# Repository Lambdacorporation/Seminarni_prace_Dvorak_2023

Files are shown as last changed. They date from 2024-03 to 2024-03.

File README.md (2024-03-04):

# Seminární práce Dvořák 2023
Tato práce je zaměřena na vytvoření vlastního fyzického 3D modelu v podobě simulátoru křižovatky ovládané jednodeskovými počítači a mikrokontrolery Raspberry Pi, které jsou propojeny pomocí SSH protokolu, a dalšími kompatibilními komponenty. Další nedílnou součástí tohoto simulátoru je Python aplikace, která slouží a je programována jako přehledný ovládací panel na sedmipalcovém multikapacitním displeji. Jejím hlavním účelem je možnost procvičování řady otázek týkajících se pravidel silničního provozu na křižovatkách.

Klíčová slova: Raspberry Pi; křižovatka; 3D simulátor; Python; SSH protokol; dotykový displej; krokový motor; auto

This project is focused on creating a custom physical 3D model in the form of an intersection simulator controlled by single-board computers and Raspberry Pi microcontrollers connected through the SSH protocol, along with other compatible components. Another integral part of this simulator is a Python application designed and programmed as a user-friendly control panel on a seven-inch multitouch display. Its main purpose is to provide the ability to practice a series of questions related to traffic rules at intersections. 

Keywords: Raspberry Pi; traffic intersection; 3D simulator; Python; SSH protocol; multitouch display; stepper motor; car

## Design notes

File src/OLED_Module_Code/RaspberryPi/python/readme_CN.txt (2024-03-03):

/*****************************************************************************
* | File      	:   Readme_CN.txt
* | Author      :   Waveshare team
* | Function    :   Help with use
* | Info        :
*----------------
* |	This version:   V1.0
* | Date        :   2020-08-28
* | Info        :   在这里提供一个中文版本的使用文档，以便你的快速使用
******************************************************************************/
这个文件是帮助您使用本例程。
由于我们的OLED屏越来越多，不便于我们的维护，因此把所有的OLED程序做成一个工程。
在这里简略的描述本工程的使用：

1.基本信息：
本例程基于树莓派4B+开发的，内核版本
	Linux raspberrypi 5.4.51-v7l+ #1333 SMP Mon Aug 10 16:51:40 BST 2020 armv7l GNU/Linux
你可以在工程的examples\中查看对应的测试例程;

2.管脚连接：
管脚连接你可以在\lib\waveshare_OLED\config.py中查看，这里也再重述一次：
SPI:
	OLED   =>    RPI(BCM)
	VCC    ->    3.3
	GND    ->    GND
	DIN    ->    10(MOSI)
	CLK    ->    11(SCLK)
	CS     ->    8
	DC     ->    25
	RST    ->    27

IIC:
	OLED   =>    RPI(BCM)
	VCC    ->    3.3
	GND    ->    GND
	DIN    ->    2(SDA)
	CLK    ->    3(SCL)
	CS     ->    8
	DC     ->    25
	RST    ->    27

3.安装库：
    sudo apt-get update
    sudo apt-get install python-pip
    sudo apt-get install python-pil
    sudo apt-get install python-numpy
    sudo pip install RPi.GPIO

或

    sudo apt-get update
    sudo apt-get install python3-pip
    sudo apt-get install python3-pil
    sudo apt-get install python3-numpy
    sudo pip3 install RPi.GPIO

4.基本使用：
由于本工程是一个综合工程，对于使用而言，你可能需要阅读以下内容：
你可以在examples\目录中查看测试程序
请注意你购买的是哪一款的OLED。
栗子1：
    如果你购买的1.3inch OLED Module (C)，那么你应该执行命令：
		sudo python OLED_1in3_c_test.py
	或
		sudo python3 OLED_1in3_c_test.py
栗子2：
    如果你购买的1.5inch RGB OLED Module，那么你应该执行命令：
		sudo python OLED_1in5_rgb_test.py
	或
		sudo python3 OLED_1in5_rgb_test.py

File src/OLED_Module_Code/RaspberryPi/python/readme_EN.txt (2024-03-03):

/*****************************************************************************
* | File      	:   Readme_EN.txt
* | Author      :   Waveshare team
* | Function    :   Help with use
* | Info        :
*----------------
* |	This version:   V1.0
* | Date        :   2020-08-28
* | Info        :   Here is an English version of the documentation for your quick use.
******************************************************************************/
This file is to help you use this routine.
Since our OLED screens are getting more and more, it is not convenient for our maintenance, so all the OLED screen programs are made into one project.
A brief description of the use of this project is here:

1. Basic information:
This routine is based on the raspberry PI 4B+ development, the kernel version:
	Linux raspberrypi 5.4.51-v7l+ #1333 SMP Mon Aug 10 16:51:40 BST 2020 armv7l GNU/Linux
You can view the corresponding test routines in the examples\ of the project;

2. Pin connection:
Pin connections can be viewed in \lib\waveshare_OLED\config.py and will be repeated here:
SPI:
	OLED   =>    RPI(BCM)
	VCC    ->    3.3
	GND    ->    GND
	DIN    ->    10(MOSI)
	CLK    ->    11(SCLK)
	CS     ->    8
	DC     ->    25
	RST    ->    27

IIC:
	OLED   =>    RPI(BCM)
	VCC    ->    3.3
	GND    ->    GND
	DIN    ->    2(SDA)
	CLK    ->    3(SCL)
	CS     ->    8
	DC     ->    25
	RST    ->    27

3.Installation library
    sudo apt-get update
    sudo apt-get install python-pip
    sudo apt-get install python-pil
    sudo apt-get install python-numpy
    sudo pip install RPi.GPIO

or

    sudo apt-get update
    sudo apt-get install python3-pip
    sudo apt-get install python3-pil
    sudo apt-get install python3-numpy
    sudo pip3 install RPi.GPIO

4. Basic use:
Since this project is a comprehensive project, you may need to read the following for use:
You can view the test program in the examples\ directory.
Please note which OLED you purchased.
eg 1:
    if you bought 1.3inch OLED Module (C)，you should type：
		sudo python OLED_1in3_c_test.py
	or
		sudo python3 OLED_1in3_c_test.py
eg 2:
    if you bought 1.5inch RGB OLED Module，you should type：
		sudo python OLED_1in5_rgb_test.py
	or
		sudo python3 OLED_1in5_rgb_test.py

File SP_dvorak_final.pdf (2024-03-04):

## Gymnázium Třebíč

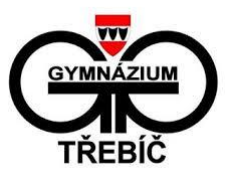
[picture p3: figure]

## Seminární práce z programování

## Simulace křižovatek pomocí fyzického 3D modelu

## Dominik Dvořák, 8.G

Vedoucí práce:
Ing. Lukáš Semerád Ph.D. | Třebíč 2023

Prohlašuji, že jsem při zpracování práce postupoval v souladu se zákonem 121/2000 Sb., o právu

autorském a o právech souvisejících s právem autorským v plném znění. Práci jsem vypracoval

samostatně pod vedením Ing. Lukáše Semeráda Ph.D. a použité zdroje informací jsem řádně uvedl

v Seznamu pramenů, Seznamu literatury a v seznamu Internetových zdrojů.

Třebíč 15. 12. 2023 | Dominik Dvořák

## Poděkování

Na tomto místě bych chtěl poděkovat všem, kteří mi s prací pomáhali a podporovali mě: v první

řadě vědecké skupině STRaDe při VUT Brno za možnost využití 3D tiskáren a poskytnutí cenných

rad k mé seminární práci, dále bych chtěl poděkovat své rodině za shovívavost a poskytnutí

podmínek k vypracování práce. A na závěr bych chtěl také poděkovat mému vedoucímu práce

a konzultantovi Ing. Lukáši Semerádovi Ph.D. za řadu cenných rad a odbornou konzultaci k mé

práci.

## Abstrakt

Tato práce je zaměřena na vytvoření vlastního fyzického 3D modelu v podobě simulátoru

křižovatky ovládané jednodeskovými počítači a mikrokontrolery Raspberry Pi, které jsou propojeny

pomocí SSH protokolu, a dalšími kompatibilními komponenty. Další nedílnou součástí tohoto

simulátoru je Python aplikace, která slouží a je programována jako přehledný ovládací panel na

sedmipalcovém multikapacitním displeji. Jejím hlavním účelem je možnost procvičování řady

otázek týkajících se pravidel silničního provozu na křižovatkách.

## Klíčová slova

Raspberry Pi; křižovatka; 3D simulátor; Python; SSH protokol; dotykový displej; krokový motor;

auto

## Abstract

This project is focused on creating a custom physical 3D model in the form of an intersection

simulator controlled by single-board computers and Raspberry Pi microcontrollers connected

through the SSH protocol, along with other compatible components. Another integral part of this

simulator is a Python application designed and programmed as a user-friendly control panel on

a seven-inch multitouch display. Its main purpose is to provide the ability to practice a series of

questions related to traffic rules at intersections.

## Keywords

Raspberry Pi; traffic intersection; 3D simulator; Python; SSH protocol; multitouch display; stepper

motor; car

Obsah

### ÚVOD

Tato práce se zabývá stavbou 3D fyzického simulátoru křižovatek, který má pomoci lépe

porozumět problematice pravidel silničního provozu na křižovatkách při výuce. Konkrétně

jsou využity při stavbě simulátoru pláty z 1 mm tlusté nerez oceli, jedno Raspberry Pi 4, čtyři

Raspberry Pi Zero, Raspberry Pi Pico WH, osm krokových motorů pro ovládání autíček na

vrchní desce a pro ovládání výhybek na ozubených drahách, čtyři OLED 1,5“ displeje pro

zobrazení dopravních značek, jeden 7“ dotykový displej, ozubené dráhy vytištěné z ABS

filamentu a moduly semaforů. Co se softwaru týče, tak je využit jako primární jazyk Python

a jeho knihovny, a SSH protokol. Práce uvádí také historii počítačů Raspberry Pi a rozbor

konkrétních modelů, dále také popisuje pravidla silničního provozu na křižovatkách.

V první části mé práce popisuji historii společnosti Raspberry Pi Foundation. Poté se věnuji

podrobnému popisu, představení a vlastnostem modelů Raspberry Pi a vybraným typům

operačních systémů, které jsou díky své jednoduchosti hardwaru a opensource licenci

dlouhodobě softwarově podporovány.

Druhá část práce je zaměřena na pravidla silničního provozu křižovatek. Zde zjišťuji, jaká

pravidla platí pro neoznačené křižovatky, ale převážně se věnuji dopravním značkám.

Dopravních značek je velké množství, ovšem křižovatek se týkají především dopravní značky

upravující přednost a světelné signalizační řízení. Toto řízení pomáhá s regulací provozu a je

užíváno převážně na vytížených místech. Všechny tyto vyhlášky nalezneme ve Sbírce zákonů ČR o provozu na pozemních komunikacích a o změnách některých zákonů (zákon o silničním

provozu).

Třetí částí je již samotné sestavení, vzhled a detailní popsání 3D simulátoru. K uvedení

simulátoru do provozu jsou potřeba krokové motory, OLED displeje, multitouch displej,

Raspberry Pi Zero WH, Raspberry Pi Pico WH a Raspberry Pi 4. Dalšími součástkami, které

zde nalezneme jsou například semafory, výhybky, ozubené koleje či modely aut. Tato auta

jezdí po vrchní desce modelu a jsou poháněna pomocí čtyř krokových motorů 28BYJ-48.

Zbylé motory ovládají „výhybky“ uprostřed simulátoru, které slouží k přesunutí autíčka na

jinou „ozubenou kolej“. Většina součástek byla vytištěna na 3D tiskárně pomocí 0,4 mm

filamentu ABS.

Poslední část mé práce věnuji operačnímu systému Raspberry OS, programovacímu jazyku

a komunikaci využité v simulátoru. Jako programovací jazyk celého modelu jsem zvolil

Python, který má na výběr velké množství knihoven. Všechny počítače Raspberry Pi spolu

komunikují pomocí SSH protokolu, který umožňuje rychlý a spolehlivý přenos příkazů.

V dnešní době známe mnoho způsobů, jak využít moderní techniku v reálném životě. Proto

mým prvním cílem při zpracovávání této práce je zvýšit povědomí o moderních možnostech

učení. Jako druhý cíl jsem si stanovil zdokonalení a prohloubení mých znalostí v oblasti

programování, představivosti a zručnosti.

### 1 RASPBERRY PI

Raspberry Pi je název pro řadu malých jednodeskových počítačů vyvíjených britskou

společností Raspberry Pi Foundation. Společnost založil Eben Upton jako neziskovou

organizaci v roce 2008 a jejím původním záměrem byl vývoj malých levných počítačů

sloužících pro výuku informatiky a robotiky ve školách. [57] [58]

Po vydání druhé generace Raspberry Pi se vytvořila dceřiná společnost Raspberry Pi Trading,

která převzala vývoj počítačů, zatímco Raspberry Pi Foundation se dále věnovala zpřístupnění

technologií co nejvíce studentům. [59]

## 1.1 Modely

Raspberry Pi Foundation dohromady vytvořila šestnáct modelů jednodeskových počítačů,

z kterých jsou k dnešnímu dni pouze tři oficiálně vyřazené a neprodejné (První generace

s 26pinovým GPIO a Raspberry Pi 4 s 1 GB RAM představená v roce 2019). Každý si může

vybrat pro své projekty ze spousty variant velikostí nebo výkonu.

### 1.1.1 Raspberry Pi model A a model B

První generace Raspberry Pi byla představena v roce 2012, a to ve dvou modelech, levnější

ale slabší model A a o něco dražší ale silnější model B. Model B byl uveden do prodeje v roce

2012, model A se o rok opozdil. [4]

Oba modely poháněl SoC čip BCM2835 od firmy Broadcom, postavený na jednojádrovém

procesoru ARM1176JZF-S od firmy ARM, a také obsahovaly 26pinový GPIO header, který

byl využit pouze v této generaci. Model A obsahoval 256 MB RAM a model B měl dvě

konfigurace RAM, jedna verze měla k dispozici také 256 MB a druhá dokonce 512 MB.

Model B navíc disponoval, oproti modelu A, ethernet portem a dvěma USB A porty namísto

jednoho, jinak byly modely i designem téměř identické. [4] [5] [6]

V roce 2014 Raspberry Pi Foundation uvedla do prodeje ještě vylepšené varianty první

generace Raspberry Pi. Nové modely dostaly označení Raspberry Pi A+ a Raspberry Pi B+.

Tyto vylepšené modely se lišily od základních velikostí operační paměti, oba modely dostaly

512 MB, a nově byly osazeny 40pinovým headrem, který se používá dodnes. Model A+ byl navíc redesignován do kompaktnějšího řešení, tudíž se mohl používat i v projektech, kde

prostor hrál velkou roli. Model B+ byl vylepšen z hardwarové stránky také. Nově měli

uživatelé k dispozici čtyři USB 2.0 porty a micro SD slot nahradil již zastaralý SD slot. [8]

### 1.1.2 Raspberry Pi 2

Druhá generace označená jako Raspberry Pi 2 měla pouze jeden model, a to model B,

představený v roce 2015. S tímto modelem je také spojena transformace firmy, od tohoto roku

totiž všechny jednodeskové počítače Raspberry Pi vyvíjí firma Raspberry Pi Trading, která se

na rozdíl od Raspberry Pi Foundation bude zabývat pouze vývojem těchto počítačů, a tak se

celý proces vývoje zrychlí a Raspberry Pi budou ještě propracovanější a kvalitnější, než byly

doposud. [59]

Raspberry Pi 2 B pohání SoC čip BCM2836 od firmy Broadcom, postavený na čtyřjádrovém

procesoru Cortex-A7 s frekvencí 0.9 GHz od firmy ARM, a ve vylepšené později vydané

variantě tohoto počítače můžeme najít SoC čip BCM2837, postavený na taktéž čtyřjádrovém

procesoru Cortex-A53 s frekvencí 1.2 GHz od ARM. Dále tento počítač má k dispozici 1 GB

operační paměti a nechybí zde ani ethernet port, HDMI port a čtyři USB 2.0 porty. [6] [10]

[12]

### 1.1.3 Raspberry Pi Zero

Ve stejném roce jako druhá generace byl ještě představen ultra kompaktní jednodeskový

počítač Raspberry Pi Zero. Tento počítač pohání stejný procesor jako první generaci, tedy

BCM2835, doplněný o 512 MB operační paměti. Rasperry Pi Zero musel kvůli své

kompaktnosti zrušit veškeré velké porty, takže na desce najdeme pouze dva micro USB porty,

jeden mini HDMI port a slot na SD kartu, 40pinový header však nijak redukovaný není

a táhne se přes celou délku desky. [14]

V roce 2017 byl vyvinut vylepšený model Raspberry Pi Zero, označený písmenem W na

konci (tedy Raspberry Pi Zero W). Písmeno W v názvu označovalo možnost bezdrátového

připojení k internetu. Tento model byl prvním kompaktním zařízením od Raspberry Pi, který

měl k dispozici bezdrátové připojení, a to konkrétně pomocí čipu BCM43143 od firmy

Broadcom. [18] [19]

### 1.1.4 Raspberry Pi 3

První model třetí generace Raspberry Pi byl vydán v roce 2016, konkrétně model

pojmenovaný Raspberry Pi 3. Tento model byl poháněn SoC čipem BCM2837B0 vyvinutým

společností Broadcom, postaveném na čtyřjádrovém 64bitovém procesoru Cortex-A53 od

firmy ARM. Stal se tak prvním počítačem Raspberry Pi, který běhel na 64bitové architektuře.

Raspberry Pi 3 (později přejmenovaný na Raspberry Pi 3 B) měl k dispozici 1 GB RAM

a porty se od předchozí generace téměř nelišili, změnil se akorát Micro USB port určený

k napájení počítače za silnější, který zvládal napětí až 2.5 A. Nově na desce přibyl ještě

WLAN a BLE čip BCM43438 od firmy Broadcom. Tento počítač tak získal ještě širší škálu

využití, právě díky bezdrátovému připojení k internetu. [6] [13] [15] [16] [17]

Zbylé dva modely třetí generace se začali prodávat v roce 2018. Levnější a slabší model

Raspberry Pi 3 A+ vyvinul výrobce jako přímého nástupce modelu Raspberry Pi A+. Tento

model měl k dispozici stejně jako předchůdce 512 MB operační paměti a jeden USB 2.0 port,

ale navíc se na desce objevil HDMI port a WLAN a Bluetooth čip BCM43438 od firmy

Cypress. Celý model byl poháněn SoC čipem BCM2837B0 s čtyřjádrovým procesorem ARM

Cortex-A53 disponujícím frekvencí 1.4 GHz. Silnější Raspberry Pi 3 B+ měl k dispozici

1 GB operační paměti, čtyři USB 2.0 porty, ethernet port a jinak všechny komponenty byly

stejné jako u Raspberry Pi 3 A+. [17] [20] [22] [23]

### 1.1.5 Raspberry Pi 4 a Raspberry Pi 400

Rok 2019 přinesl čtvrtou generaci počítačů Raspberry Pi, složenou sice z jednoho modelu

Raspberry Pi 4 B, ale za to dokonce ve třech variantách. Varianty se lišily pouze velikostí

operační paměti a cenou, jinak byly naprosto identické. Konkrétně mohly tyto počítače

obsahovat 1 GB, 2 GB nebo 4 GB LPDDR4 operační paměti. Všechny varianty poháněl SoC

čip BCM2711, uvnitř kterého se nacházel 64bitový čtyřjádrový procesor ARM Cortex-A72

s frekvencí 1,8 GHz. Nově se na desce objevily kromě USB 2.0 portů také rychlejší USB 3.0

porty, a také se microUSB napájecí port změnil na novější USB-C port. [24] [25] [26]

Čtvrtá generace Raspberry Pi se ještě v roce 2020 rozšířila o model s 8 GB RAM, a nově byl

představen designově úplně odlišný jednodeskový počítač Raspberry Pi 400, zabudovaný

v klávesnici. Tento „klávesnicový“ počítač byl představen pouze v jedné variantě se stejnými

komponenty jako Raspberry Pi 4 se 4 GB operační paměti. [27] [28] [29]

### 1.1.6 Raspberry Pi Zero 2

Rok 2021 také nebyl mrtvý v oblasti vývoje Raspberry Pi. Představily se hned dva

jednodeskové počítače. Jedním z nich byla druhá generace Raspberry Pi Zero. Tento počítač

obsahoval SoC RP3A0 (předělaný SoC BCM2710A1) s 512 MB operační paměti

a 64bitovým čtyřjádrovým procesorem ARM Cortex-A53 s frekvencí 1 GHz. Jinak byl oproti

předchozí generaci naprosto identický. [30] [31]

### 1.1.7 Raspberry Pi Pico

Druhým představeným počítačem v roce 2021 byl Raspberry Pi Pico, sloužící spíše jako

microcontroller ve všemožných projektech. Tento miniaturní jednodeskový počítač obsahoval

SoC RP2040, vyvinutý přímo společností Raspberry Pi, poháněný dvoujádrovým procesorem

ARM Cortex-M0+ s frekvencí 133 MHz s 264 kB operační paměti a zabudovaným 2 MB

flash úložištěm. Raspberry Pi Pico neobsahuje 40pinové GPIO jako ostatní modely, ale pouze

26pinové, kvůli úspoře místa. O rok později byla představena vylepšená varianta Raspberry Pi

Pico, nazvaná Raspberry Pi Pico W, která navíc oproti předchozímu modelu obsahovala

WLAN a Bluetooth čip, díky němuž se ještě více rozšířily možnosti, jak tento microcontroller

využít. [32] [33]

### 1.1.8 Raspberry Pi 5

Po vydání čtvrté generace spousta lidí netrpělivě čekalo na pátou, ale musely čekat relativně dlouho. Čtyři roky totiž Raspberry Pi skrytě vyvíjelo a testovalo nový model, o kterém občas

nějaký článek vyšel, i když většinou moc nenapověděl. Pátá generace přišla poněkud

nečekaně v roce 2023 a to ve dvou modelech. Levnější varianta se 4 GB operační paměti

a dražší s 8 GB. Oproti čtvrté generaci byla pátá solidním vylepšením. Obsahovala dva USB

2.0 a dva USB 3.0 porty s rychlostí přenosu dat až 5 Gbps, které ovládal oproti čtvrté generaci

nový I/O čip RP1 vyrobený samotným výrobce počítačů Raspberry Pi ve spolupráci s firmou

Broadcom, jedná se o druhý čip vyrobený Raspberry Pi, který byl použit v jejich počítačích.

Dále na rozdíl od předešlých generací obsahovala RTC poháněné externí baterií, jako to

můžeme najít u klasických stolních počítačů. Celý model poháněl SoC BCM2712 vyrobený

16nanometrovou technologií od firmy Broadcom s 64bitovým procesorem ARM Cortex-A76

s frekvencí 2.4 GHz. Podle výrobce byla pátá generace dvakrát až třikrát rychlejší než čtvrtá,

právě díky novému procesoru. [34] [35] [36]

## 1.2 Operační systémy na Raspberry Pi

Každý počítač Raspberry Pi běží na nějakém operačním systému. Operačních systémů, které

jsou podporovány na Raspberry Pi je velké množství hlavně díky jednoduchosti hardwaru

a opensource licencích na Raspberry Pi, proto zde bude vypsán jen výčet několika málo

systémů.

### 1.2.1 Raspberry Pi OS

Raspberry Pi OS je komunitou a Raspberry Pi Foundation aktivně vyvíjený opensource

operační systém. Tento systém je doporučeno používat právě díky kompatibilitě s hardwarem

a vývojem společností, která vyvinula jak hardware, tak software. Raspberry Pi OS byl vydán

v roce 2012 a jako základ pro něj posloužil Debian, díky čemuž podporuje většinu balíčků

určených právě pro Debian.

Samotný systém obsahuje přes 35 000 balíčků, ve kterých se nachází i například aplikace pro

výuku programování. Raspberry Pi OS lze ovládat jak pomocí grafického rozhraní, tak

pomocí příkazového řádku. Jako většina linuxových distribucí je i tento operační systém

konfigurovatelný. Konfigurace zde probíhá pomocí Raspberry Pi Configuration nástroje,

pomocí nějž můžeme například povolit SSH protokol, nebo přetaktovat procesor. [1] [38] [39]

### 1.2.2 Ubuntu MATE

Základ Ubuntu MATE leží na známé linuxové distribuci Ubuntu. Ve zkratce jde o odlehčený

operační systém Ubuntu přestavěný pro Raspberry Pi počítače, avšak lze použít i pro klasické

desktopy, které už mají zastaralé nebo slabé komponenty. [40]

### 1.2.3 Windows 10 IoT Core

Vývoj Windows 10 IoT Core je plně zastřešen společností Microsoft, a je kompatibilní

prakticky s každým zařízením postaveném na ARM procesoru, mezi něž se řadí i Raspberry

Pi. Tento operační systém slouží pro správu Internet of Things. Raspberry Pi s Windows 10

IoT Core můžeme tedy využít například pro správu chytré domácnosti. [41]

### 1.2.4 Kali Linux

Jedna z mnoha variant Kali Linuxu se vyvíjí právě na ARM zařízení, jako jsou například

ODROID, CuBox nebo Raspberry Pi. Tento operační systém slouží pro testování zabezpečení

například Wi-Fi sítě pomocí průniku. Kali Linux je také nechvalně proslulý využitím

k nelegálním činnostem, například k DDoS útokům právě díky množství testovacích

možností. [42]

## 1.3 Vlastnosti Raspberry Pi

Na Raspberry Pi lze programovat v mnoha programovacích jazycích, jako například Python,

C++, Java, Perl nebo Scratch. Nejčastěji se využívá Python, hlavně díky velkému množství

knihoven určených pro Raspberry Pi. Díky GPIO pinům se dá k Raspberry Pi připojit velké

množství komponent, které se následně ovládají pomocí programu vytvořeného uživatelem.

Mezi komponenty, které lze připojit k GPIO patří například menší displeje, motory nebo LED

diody. Dále se dá k Raspberry Pi připojit pomocí USB portů například myš a klávesnice

a pomocí HDMI můžeme připojit monitor. Například Raspberry Pi 4 B podporuje až dva 4K

monitory, tudíž můžeme počítače Raspberry Pi využít třeba i jako multimediální přehrávač,

právě díky vysoké kvalitě obrazu, kterou procesor na Raspberry Pi zvládá. [24] [43] [44]

### 2 KŘIŽOVATKY

Pro pochopení základní funkčnosti simulátoru, je potřeba znát pravidla silničního provozu na

křižovatkách. Hlavní pravidla silničního provozu na křižovatkách naleznete v této kapitole.

## 2.1 Obecná a místní úprava provozu

Obecná a místní úprava provozu na pozemních komunikacích je definována v §61 zákona

č. 361/2000 Sb. Obecná úprava provozu je dána zněním tohoto zákona, podle ní mimo jiné

platí přednost protijedoucím vozidlům při odbočování vlevo. Místní úprava provozu na

pozemních komunikacích je úprava provozu na pozemních komunikacích provedená

dopravními značkami, světelnými signály nebo dopravními zařízeními. Místní úprava je

nadřazena obecné úpravě provozu, o čemž pojednává §76. [2]

## 2.2 Neoznačené křižovatky

„Podle §22 není-li křižovatka rozlišena dopravními značkami upravujícími přednost, není-li

řízena světelnými signály, nebo není-li řízena policistou, platí přednost v jízdě vozidel

přijíždějících zprava. Přednost zprava se uplatní také vzájemně mezi vozidly přijíždějícími po

hlavní silnici, a pak i mezi vozidly přijíždějícími po vedlejší silnici tam, kde dle dodatkové

tabulky vede hlavní silnice do zatáčky.“ [2]

## 2.3 Dopravní značky na křižovatkách

Je-li hlavní a vedlejší pozemní komunikace rozlišena dopravními značkami upravujícími

přednost, řídí se řidič, jezdec na zvířeti, průvodce hnaných zvířat nebo organizovaná skupina

chodců značkou příslušnou pro jejich směr jízdy. Vyobrazení a význam dopravních značek je

stanoven vyhláškou č. 294/2015 Sb., která je prováděcí vyhláškou k zákonu č. 361/2000 Sb.,

a rozděluje dopravní značky na svislé a vodorovné, které se dále dělí podle mnoha dalších

kategorií. [2]

2.3.1 Dělení dopravních značek podle §62 zákonu č. 361/2000 Sb.

Podle §62 zákonu č. 361/2000 Sb. se dopravní značky svislé dělí na stálé, upevněné

konstrukcí pevně k zemi nebo k budově, proměnné, jejichž provedení se může měnit (často jde o nějaký displej), nebo přenosné, které slouží na určitém místě pouze dočasně. Stejně

rozděluje dopravní značky i §1 vyhlášky č. 294/2015 Sb. Rozdělení dopravních značek se

tedy vyskytuje ve dvou zákonech. [2]

### 2.3.2 Značky upravující přednost

Na křižovatkách můžeme potkat většinou svislé značky upravující přednost, které určuje §5.

Jde o značky: Hlavní pozemní komunikace, Konec hlavní pozemní komunikace, Dej přednost

v jízdě!, Stůj, dej přednost v jízdě!, Křižovatka s vedlejší pozemní komunikací nebo Dej

přednost v jízdě tramvaji!. Dále se však na křižovatce mohou vyskytovat i značky vodorovné,

které definuje §12 a konkrétně jde o příčné čáry, jenž se nachází na vedlejších pozemních

komunikacích většinou těsně před křižovatkou. Příčné čáry existují pouze tři: Příčná čára

souvislá (vyznačuje hranici křižovatky), Příčná čára souvislá se symbolem „Dej přednost

v jízdě!“ (má stejnou funkci jako pouze Příčná čára souvislá), Příčná čára souvislá s nápisem

STOP (vyznačuje místo, kde je řidič povinen zastavit vozidlo). [2]

### 2.3.3 Světelné signalizační řízení

Světelné signály pomáhají hlavně na vytíženějších křižovatkách s regulací provozu. Definuje

je §13 z vyhlášky č. 294/2015 Sb.

Nejčastěji se na křižovatkách setkáme s tříbarevnou soustavou s plnými signály, těmi signály jsou: „Signál s červeným světlem „Stůj!“ (Řidič je povinen zastavit vozidlo před dopravní

značkou „Příčná čára souvislá“, „Příčná čára souvislá se symbolem Dej přednost v jízdě!“

a „Příčná čára souvislá s nápisem STOP“, a kde taková značka není, před světelným signalizačním řízením), Signál se žlutým světlem „Pozor!“ (Řidič je povinen zastavit vozidlo

před dopravní značkou „Příčná čára souvislá“, „Příčná čára souvislá se symbolem Dej

přednost v jízdě!“ a „Příčná čára souvislá s nápisem STOP“, a kde taková značka není, před

světelným signalizačním řízením. Je-li však vozidlo při rozsvícení tohoto signálu již tak blízko,

že by řidič nemohl bezpečně zastavit, smí pokračovat v jízdě. Svítí-li světlo tohoto signálu

přerušovaně, nejde o křižovatku s provozem řízeným světelnými signály.) a Signál se zeleným světlem (Řidič může pokračovat v jízdě, a dodrží-li ustanovení o odbočování, může odbočit

vpravo nebo vlevo, přičemž musí dát přednost chodcům přecházejícím ve volném směru po

přechodu pro chodce a cyklistům přejíždějícím ve volném směru po přejezdu pro cyklisty).“

[2]

Dále se můžeme setkat na křižovatkách se tříbarevnou soustavou se směrovými signály nebo

se tříbarevnou soustavou s kombinovanými směrovými signály, kde signály znamenají pro

řidiče povinnost zastavit vozidlo nebo možnost pokračovat v jízdě jen ve směru, kterým

ukazuje šipka. [2]

### 3 HARDWARE VYUŽITÝ V SIMULÁTORU

Simulátor křižovatky využívá hardware v poměrně velkém množství. K uvedení simulátoru

do funkčního stavu byly potřeba krokové motory, OLED displeje, multitouch displej,

Raspberry Pi Zero WH, Raspberry Pi Pico WH a Raspberry Pi 4. Jednotlivě rozepsané

hardwarové součástky, které byly využity v simulátoru naleznete v této části.

## 3.1 Motory

Modely aut jezdící po vrchní desce modelu jsou poháněny pomocí krokových motorů 28BYJ-

48. Krokový motor je motor, u kterého lze pomocí mikrokontroleru ovládat nejen časový

údaj, po který bude zapnut, ale také můžeme regulovat, o kolik stupňů se motor otočí.

Ve zkratce jde o motor se zabudovaným enkodérem. Model krokového motoru 28BYJ-48 byl

zvolen kvůli jeho malé velikosti, malé ceně a relativně velké spolehlivosti. Na pohon malých

modelů aut není potřeba silný motor, jde jen o přesnost a v tomto ohledu byl daný motor

velmi vhodný.

Ke krokovému motoru 28BYJ-48 byl využit řadič ULN2003, který byl doporučen výrobcem

krokového motoru a spolupracuje s motorem spolehlivě.

Motorů 28BYJ-48 bylo využito dohromady osm. Čtyři krokové motory jsou po jednom

zapojeny do Raspberry Pi Zero WH a každý z nich ovládá jedno autíčko na horní desce

simulátoru. Na hřídel těchto motorů jsou připevněny ozubená kola, pomocí kterých se motor

pohybuje po „ozubené koleji“ a hýbe tak i autíčkem. Zbylé čtyři krokové motory ovládají

„výhybky“ uprostřed simulátoru, které slouží k přesunutí autíčka na jinou „ozubenou kolej“,

a jsou zapojeny do dohromady dvou Raspberry Pi Pico WH. Přesné zapojení jednotlivých

motorů naleznete v tabulce níže (Tab. 1):

Raspberry Pi
Zero WH

Krokový motor
Řadič ULN2003 | Krokový motor
17/16 | 4 | 1
18/7 | 3 | 2
23/6 | 2 | 3
22/13 | 1 | 4
5V | VCC | 5
GND | GND

Tab. 1: Zapojení krokového motoru 28BYJ-48 s řadičem ULN2003 do Raspberry Pi Zero WH

## 3.2 Displeje

### 3.2.1 Displeje pro zobrazení dopravních značek

Pro zobrazení dopravních značek byly pro jednoduchost měnění z jedné značky na druhou

využity displeje. V tomto simulátoru byly zvoleny 1,5palcové RGB OLED displeje od firmy

WaveShare z důvodu přesného zobrazení barev a ideální velikosti displeje. Cena v tomto

případě nehrála roli, protože v době vytváření simulátoru byly displeje s jinými technologiemi

vyprodány, jinak by byly pravděpodobně zvoleny displeje s technologií LCD nebo TFT právě

z důvodu mnohonásobně menší ceny a dostačující kvality. Kvůli technologii připojení displeje

SPI se nedá zapojit více než jeden displej do jednoho Raspberry Pi Zero WH, a tudíž musel

být každý z displejů zapojen do jiného Raspberry Pi Zero WH. Tento displej využívá napětí

3.3 V, a i proto byl vhodný pro zapojení do Raspberry Pi Zero WH, které má právě jeden pin

uzpůsobený na napájení zařízení s napětím 3.3 V. Přesné zapojení OLED displeje do

Raspberry Pi Zero WH naleznete v tabulce níže (Tab. 2):

OLED

Raspberry Pi Zero WH
BCM2835 | Board
VCC | 3.3V | 3.3V
GND | GND | GND
DIN | MOSI | 19
CLK | SCLK | 23
CS | CE0 | 24
DC | 25 | 22
RST | 27 | 13

Tab. 2: Zapojení 1,5palcového OLED displeje do Raspberry Pi Zero WH [7]

### 3.2.2 Displej pro zobrazení GUI

Pro jednoduchost ovládání simulátoru a zobrazení UI byl vybrán 7palcový RGB LCD

multitouch displej od firmy WaveShare. Displej má rozlišení 1024 x 600 pixelů, ale

softwarově lze rozlišení upravit až na 1980 x 1080. V simulátoru je rozlišení displeje

ponecháno na 1024 x 600 pixelů z důvodu lepší čitelnosti a lepšího ovládání prstem. Tento

displej obsahuje pět hardwarových tlačítek pro ovládání: Power (zapne nebo vypne displej),

Menu (zapne se přehledné menu se základním nastavením displeje, po zapnutí menu se

tlačítko změní na tlačítko pro potvrzení), Exit (tlačítko pro návrat), dále displej ještě obsahuje

tlačítko pro pohyb nahoru nebo dolů a tlačítko pro pohyb doleva nebo doprava, pomocí

kterých lze ovládat menu nebo jas displeje. Pro zajištění funkčnosti 7palcového displeje bylo

potřeba přidat do konfiguračního systémového souboru přidat tyto řádky kódu:

hdmi_force_hotplug=1

config_hdmi_boost=10

hdmi_group=2

hdmi_mode=87

hdmi_cvt 1024 600 60 6 0 0 0

## 3.3 Semafory

Semafory jsou tvořeny modulem semaforu, který spojuje tři PWM LED diody pomocí PCB

desky, a zjednodušuje tak práci při zapojování těchto LED diod. Obsahuje dohromady čtyři piny na zapojení (R, Y, G, GND), kde R, Y a G se zapojí do libovolného pinu na Raspberry Pi

Pico a GND pin se zapojí do Ground pinu.

Každá LED dioda lze ovládat zvlášť, a u každé lze měnit i její svítivost. Tento modul byl

zvolen z důvodu lepší vizualizace reálné křižovatky. [45]

## 3.4 Ostatní komponenty využité v simulátoru

### 3.4.1 Součástky vytištěné pomocí 3D tisku

Většina dalších součástek simulátoru byla vytištěna na 3D tiskárně pomocí 0,4 mm filamentu

ABS (akrylonitril-butadien-styren). Součástky vytištěné z ABS jsou relativně odolné, a lze tak

do nich například po vytištění ještě vyvrtat díru, aniž by se součástky rozpadly.

### 3.4.2 Součástky vytvořené pomocí CNC laseru

Samotná hlavní konstrukce modelu simulátoru tvaru kvádru je vytvořena z milimetrových

plátů nerez oceli, do které je pomocí CNC laseru vypáleno několik děr, pomocí kterých lze

propojit vnitřní část konstrukce s vnější částí (např. ovládání autíčka na vrchní desce pomocí

motoru umístěného uvnitř kvádru). Technický výkres kvádru naleznete na obrázcích níže

(obr. 2, 3, 4, 5)

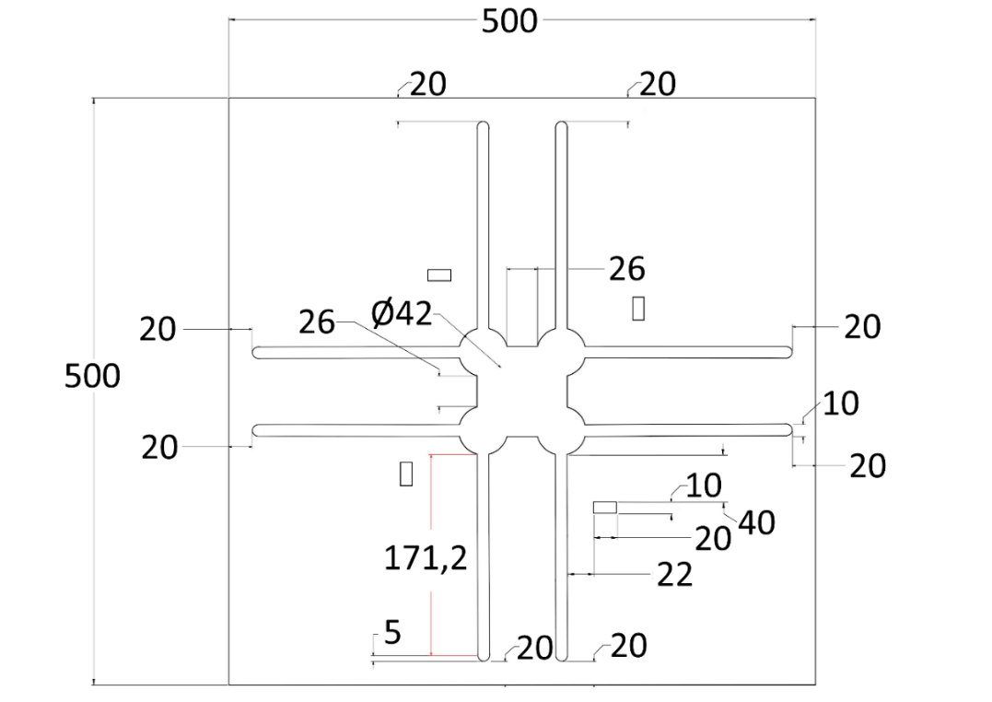
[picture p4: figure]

Obr. 2: Technický nákres vrchní stěny kvádru, 2023

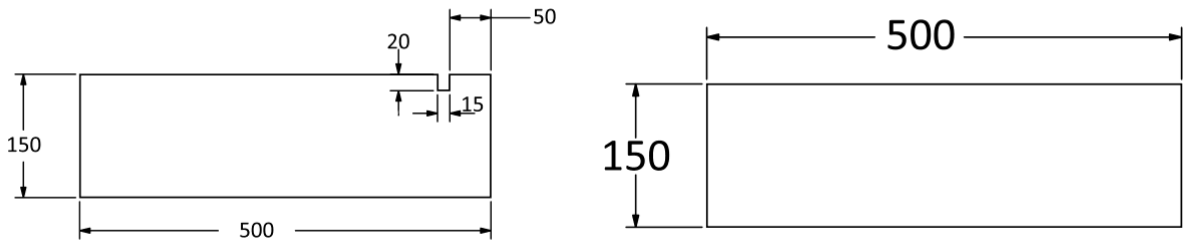
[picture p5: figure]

Obr. 3: Technický nákres přední stěny kvádru (a), zadní stěny kvádru (b), 2023

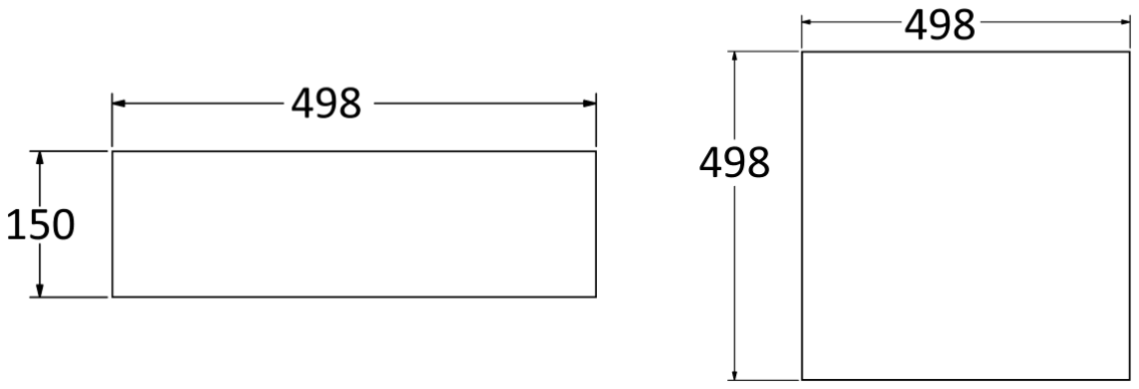
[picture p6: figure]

Obr. 4: Technický nákres boční stěny kvádru (a), spodní stěny kvádru (b), 2023

### 3.4.3 Cena hardwaru

Cena veškerých hardwarových komponent pro sestavení simulátoru byla poměrně vysoká,

mezi nejdražší součástky patří jednodeskové počítače Raspberry Pi a milimetrové pláty

z nerez oceli. Celková částka byla vyčíslena na 15 119 Kč. Celý ceník všech součástek

naleznete v tabulce níže (Tab. 3):

Název položky | Cena (v Kč)
Raspberry Pi 4B | 2 069
7palcový displej | 1 739
4x 1,5palcový OLED displej | 1 876
5x Micro USB kabel | 445
4x Raspberry Pi Zero WH | 1800
Raspberry Pi Pico WH | 209
5x microSDHC | 995
Milimetrové pláty z nerez oceli + práce CNC laseru | 1 500
DuPont kabely | 378
Filament | 2 000¹
8x krokový motor s řadičem | 568
4x semafor | 76
Zdroj pro Raspberry Pi Zero WH | 664
Šrouby a ostatní součástky | 800
Celkem | 15 119

Tab. 3: Ceník veškerého hardwaru využitého na stavbu 3D modelu

## 3.5 Mechanismy použité v simulátoru

Pro pohyb autíček po vrchní desce simulátoru byly využity ozubené kolejnice (obr. 6)

a ozubená kola (obr. 7), vytištěná na 3D tiskárně, které umožňují plynulý a přesný pohyb.

Ozubené kolejnice drží na „sloupcích“ vyrobených ze dvou šroubů spojených dohromady

(vrchní šroub M2 a spodní M5). Celý princip pohybu spočívá na krokovém motoru, na kterém

je přidělané ozubené kolo, pomocí kterého se motor pohybuje po ozubené kolejnici, na kterou

je navíc přidělán pomocí „krabičky“ z 3D tisku (obr. 7). „Krabička“ vyvíjí menší tlak na

kolejnici, díky čemuž motor z kolejnice nemůže nikdy vyjet pryč.

1 Cena pouze orientační (pravděpodobně je vyšší, než je uvedena)

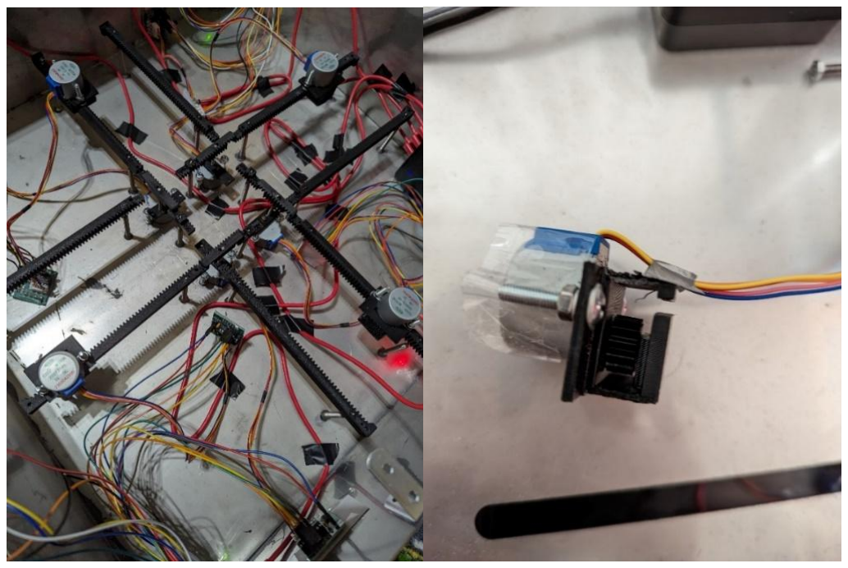
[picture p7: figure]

Obr. 6: Vnitřní část modelu s ozubenými kolejnicemi, 2023

Obr. 7: Krokový motor s ozubeným kolečkem a „krabičkou“, 2023

Pro zatočení autíčka na křižovatce se využívá princip výhybky. Na krokovém motoru

upevněném na vnitřní části dna je připevněna ozubená kolejnice (obr. 8), kterou lze za použití

tohoto motoru otáčet, a přesouvat tak motory s autíčky na další statické kolejnice, čímž auta

zatočí.

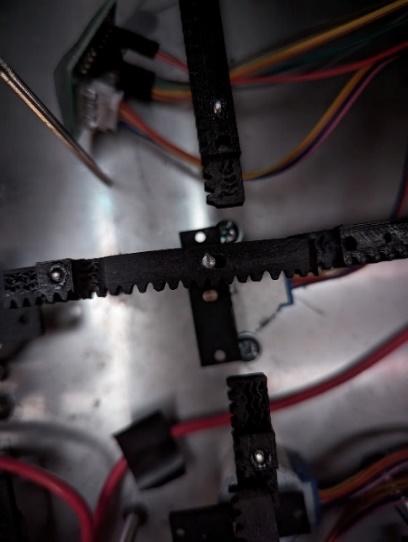
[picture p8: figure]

Obr. 8: Krokový motor s otočnou ozubenou kolejnicí, 2023

### 4 SOFTWARE VYUŽITÝ V SIMULÁTORU

Ke správnému chodu simulátoru je třeba, mimo hardwarové, také softwarová část. Všechny

programy pro ovládání simulátoru jsou tvořeny pomocí programovacího jazyka Python,

včetně mnoha knihoven pro tento jazyk. Nedílnou součást softwaru v simulátoru tvoří

komunikace mezi jednotlivými počítači, kterou zajišťuje SSH protokol. Více o softwaru

použitém v simulátoru si můžete přečíst v této části.

## 4.1 Raspberry Pi OS

Každý z počítačů Raspberry Pi 4 a Raspberry Pi Zero, využité v simulátoru, běží na

operačním systému Raspberry Pi OS, uloženém na SD kartě. Raspberry Pi OS je operační

systém postavený na Debianu, který je primárně určen pro počítače od firmy Raspberry Pi.

Díky tomu, že byl vyvíjen právě z Debianu, tak téměř jakýkoliv balíček nebo rozšíření určený

pro Debian je funkční i na Raspberry Pi OS. Velkou výhodou používání tohoto operačního

systému je jeho aktivní vývoj a pravidelné aktualizace. V základním nastavení tohoto

operačního systému se musí spustit aktualizace pokaždé manuálně. Ve všech počítačích

v simulátoru je ale využíván balíček Unattended Upgrades, které aktualizuje operační systém

automaticky, a tím pádem není potřeba zapínat terminál a celý proces aktualizace se tím velmi

zjednoduší. [1][38][46]

## 4.2 Python

Jako programovací jazyk pro programování GUI i funkční stránky programu simulátoru byl

zvolen Python. Tento programovací jazyk byl vybrán na základě předchozích testování mezi

jazykem C a Pythonem, ve kterých bylo zjištěno, že oproti programovacímu jazyku C má

Python na výběr větší množství knihoven, které jsou potřebné k provozu mého simulátoru,

a navíc Python spolupracuje s Raspberry Pi a ostatním hardwarem mnohem lépe než jazyk C.

Python má ovšem i své nevýhody, jako například rychlost provedení příkazů, kvůli které musí

uživatel simulátoru delší dobu (asi 5 sekund) počkat, než se spustí názorná ukázka situace

křižovatky. Tento problém byl vyřešen tím, že na něj program při spuštění sám uživatele

upozorní. I přes svoje neduhy je ale Python pro tento projekt vhodnější než jazyk C. [3][38]

### 4.2.1 Knihovny

Pro správné ovládání simulátoru jazykem Python bylo využito vícero knihoven, které zajišťují

například komunikaci mezi jednotlivými Raspberry Pi nebo komunikaci mezi Raspberry Pi

a dalším hardwarem.

### 4.2.1.1 Knihovna os

Knihovna os může přistupovat k jednotlivým souborům v počítači a otevírat je, nebo je měnit.

Pomocí os jsou definovány proměnné pro využití knihovnou sys. [47]

### 4.2.1.2 RPi.GPIO

Knihovna RPi.GPIO slouží pro ovládání GPIO pinů v počítačích Raspberry Pi. Tato knihovna

je využita pro ovládání ostatního hardwaru, jako například motorů nebo OLED displejů. [48]

### 4.2.1.3 Knihovna logging

Knihovna logging je jednou z nejzákladnějších knihoven Pythonu, a slouží k vyhledávání

chyb v kódu. [49]

### 4.2.1.4 Knihovna time

Knihovna time slouží k používání času v Python scriptech. Knihovna time je využita

k nastavení doby čekání u motorů nebo u OLED displejů. [50]

### 4.2.1.5 Pillow

Knihovna Pillow přidává do Pythonu možnost zpracování, rozpoznávání a vykreslování

obrázků. V simulátoru je tato knihovna využívána k vykreslování obrázků na OLED displeje.

[51]

### 4.2.1.6 Waveshare OLED

Firma Waveshare vytvořila ke svým OLED displejům i oficiální knihovny, které slouží ke

konfiguraci OLED displejů. Tyto knihovny jsou využívány v simulátoru k zjednodušení práce

s OLED displeji, na kterých jsou vyobrazeny dopravní značky.

### 4.2.1.7 Knihovna subprocess

Knihovna subprocess umožňuje Pythonu spustit více příkazů najednou. V simulátoru tato

knihovna umožňuje například spuštění více motorů najednou nebo připojení Raspberry Pi 4

pomocí SSH protokolu k více počítačům současně, a tím výrazně urychlit proces spuštění 3D

vizualizace průběhu křižovatky. [52]

### 4.2.1.8 CustomTkinter

Knihovna CustomTkinter přidává do jazyku Python mnoho možností k vytvoření moderního

GUI, které funguje a vypadá stejně na všech platformách podporujících Python. Tato

knihovna byla vytvořena z knihovny Tkinter, které rovněž slouží k podobnému účelu, tedy

tvorby uživatelského rozhraní, ale nedokáže vytvořit moderní widgety a celé GUI vypadá

velice zastarale a nepřehledně. Pomocí CustomTkinter je vytvořeno uživatelské rozhraní na

7palcové obrazovce v simulátoru. [53]

### 4.2.1.9 Paramiko

Knihovna Paramiko implementuje do jazyku Python podporu SSH protokolu, pomocí kterého

lze přesunovat soubory mezi zařízeními, nebo ovládat z jednoho zařízení jiné. V simulátoru je

knihovna Paramiko velice důležitou součástí, protože pomocí SSH protokolu je zavedena

komunikace mezi hlavní Raspberry Pi 4 a ostatními počítači. [54]

## 4.3 SSH protokol

Všechny počítače Raspberry Pi v simulátoru spolu komunikují prostřednictvím SSH

protokolu. SSH protokol je end-to-end encrypted kanál, který propojuje dvě zařízení

připojené k internetu. Pomocí SSH si mohou dvě zařízení mezi sebou posílat nejenom

příkazy, ale i soubory, navíc je tento kanál velice dobře zabezpečen proti vnějšímu vniknutí,

takže je hojně využíván při i složitějších projektech. Při propojení dvou zařízení na stejné síti

tak hrozí nebezpečí pouze na minimální úrovni, nicméně pokud útočník získá SSH klíč

z jednoho z mnoha zařízení, potom už je hrozba velká. [55][56]

Tento způsob jsem zvolil jako vhodný z mnoha důvodů:

- Počítače Raspberry Pi nespolupracují mezi sebou pomocí kabelového připojení (které

je nejvíce bezpečné proti vnějšímu proniknutí), proto jsem musel zvolit jinou

dostatečně zabezpečenou metodu.

- Pomocí SSH protokolu lze přesunovat data velmi rychle a spolehlivě. V tomto

projektu potřebuji, aby zadané příkazy vždy proběhli co nejdříve. V těchto ohledech je

SSH protokol lepší než Bluetooth, které při testování nefungovalo vždy.

- Jednoduchost implementace příkazů na posílání dat do programu.

### 5 APLIKACE

Pro lepší přehled a ovládání simulátoru, byla implementována do 7palcové dotykové

obrazovky přehledná aplikace, vytvořená v jazyku Python s pomocí knihovny CustomTkinter,

obsahující obrázky jednotlivých křižovatek (Obr. 9), které si může uživatel kliknutím spustit,

a otestovat znalost pravidel silničního provozu pomocí jednoduchého kvízu se třemi

odpověďmi (Obr. 10), kde po zvolení a potvrzení jedné možnosti může uživatel spustit 3D

simulaci pomocí autíček napojených na krokové motory. Správná možnost se po zvolení

obarví zeleně (Obr. 11), špatná červeně (Obr. 12).

Aplikace byla vytvořena tak, aby se mohla dále rozšiřovat o více křižovatek, ale i nových

funkcí. Pro lepší přehlednost kódu aplikace bylo využito tzv. Object-oriented programming

[63].

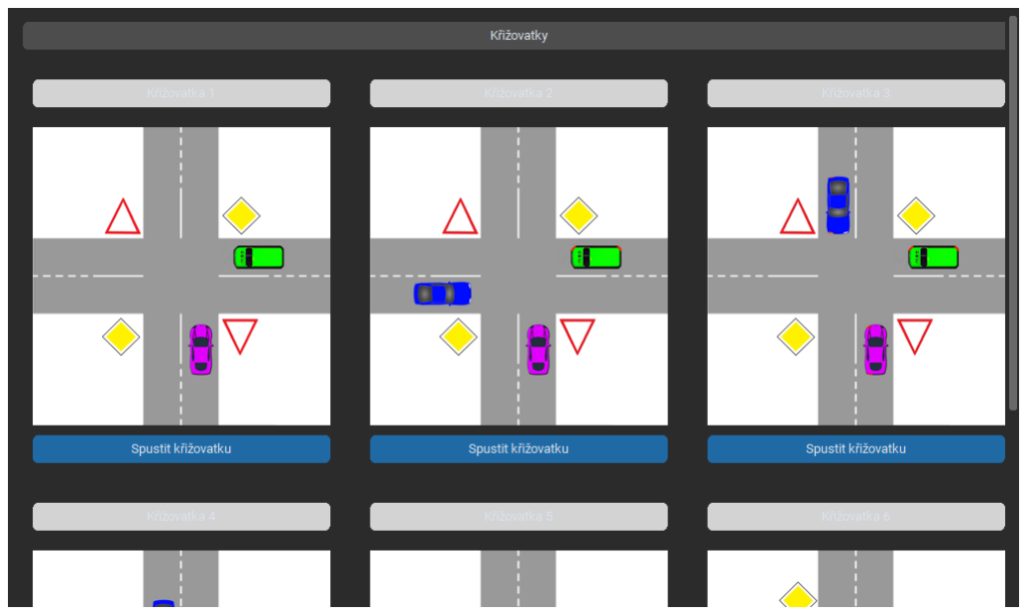
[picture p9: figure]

Obr. 9: Ukázka hlavního rozcestníku v aplikaci, 2023

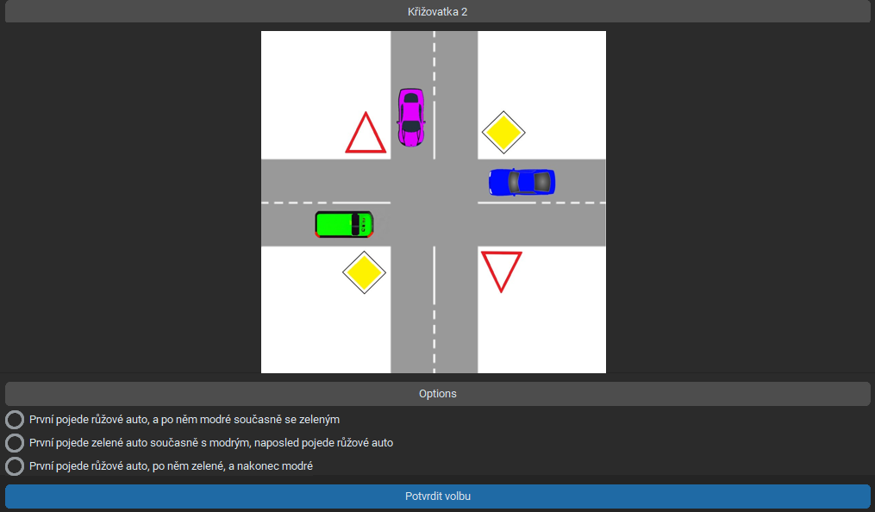
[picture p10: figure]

Obr. 10: Ukázka GUI levelu, 2023

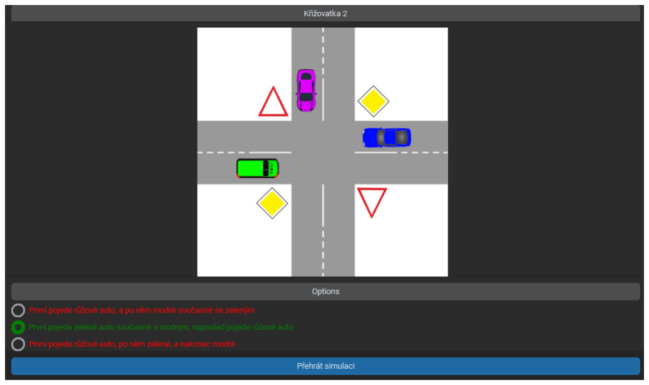
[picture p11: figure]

Obr. 11: Ukázka zvolení správné odpovědi, 2023

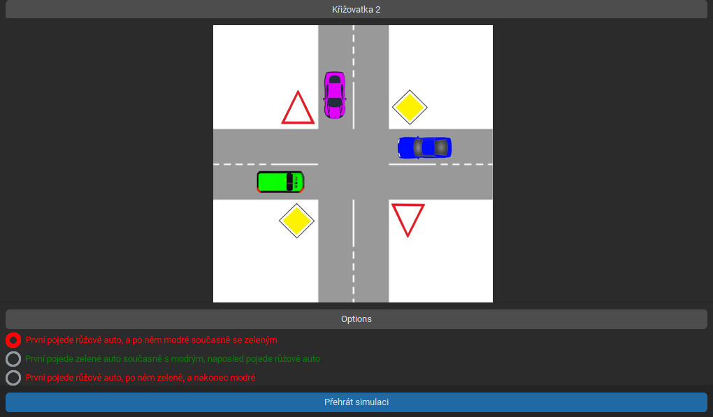
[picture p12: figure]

Obr. 12: Ukázka zvolení špatné odpovědi, 2023

## 5.1 Adresářová struktura

Celý | program | je | možné | nalézt | na | https://github.com/Lambdacorporation/
Seminarni_prace_Dvorak_2023. (https://github.com/Lambdacorporation/%20Seminarni_prace_Dvorak_2023) Strukturu tohoto média naleznete níže:
README.md | Stručný popis obsahu

src

- Levely_UI | Program pro zobrazení GUI
- OLED_Module_Code | Knihovna funkcí pro OLED displeje
- levely | skripty pro krokové motory v jednotlivých levelech
- modely | 3D modely jednotlivých součástí
- obrázky | obrázky použité v GUI a v této práci

## ZÁVĚR

Hlavním cílem bylo vytvoření 3D modelu pro simulaci křižovatek, s využitím

jednodeskového počítače Raspberry Pi, který má pomoct lépe porozumět pravidlům

silničního provozu na křižovatkách. Protože cílovou skupinu tvoří hlavně mladší žáci

základních škol, bylo nutné vytvořit i přehlednou aplikaci zobrazenou na displeji, pomocí

které se může simulátor ovládat.

V teoretické části jsou zahrnuty jednotlivé vlastnosti a funkce počítačů Raspberry Pi. Dále

teoretická část obsahuje výpis základních pravidel silničního provozu na křižovatkách, které

jsou nutné pro pochopení funkčnosti simulátoru.

V praktické části jsou uvedeny jednotlivé hardwarové prvky a mechanismy použité při stavbě

3D modelu. Následuje výpis softwarových prvků použitých pro zajištění funkčnosti hardwaru,

a také výpis softwaru využitého pro vytvoření aplikace zobrazené na displeji. Celý model

a aplikace jsou tvořeny tak, aby co nejlépe mezi sebou spolupracovali. Aplikace je tvořena

jako přehledný panel pro ovládání, aby se v ní vyznal každý uživatel.

Při návrhu 3D modelu bylo potřeba nejprve navrhnout jeho samotný tvar. Do vrchní desky

byly vyříznuty pomocí CNC laseru díry tak, aby vrchní deska nepřekážela tyčkám, na kterých

jsou napojena autíčka, a aby jimi mohly procházet kabely ven z modelu.

Dále bylo nutné vymyslet mechanismus pro pohyb autíček po vrchní desce. Nakonec byl

použit mechanismus kolejnic, po kterých se pomocí ozubených koleček pohybují motory, na

nichž jsou napojeny tyčky s autíčky.

Pro vývoj aplikace byl využit jazyk Python z důvodu oficiální podpory počítačů Raspberry Pi

a výrobců ostatního hardwaru využitého v 3D modelu. Aplikace bude sloužit jako základ pro

přidávání dalších křižovatek a jiných kvízových otázek. Celý program je možné nalézt na

https://github.com/Lambdacorporation/Seminarni_prace_Dvorak_2023.

Výsledný 3D fyzický model pro simulaci křižovatek je možné využít nejen pro výuku

pravidel silničního provozu žáků na základní škole, ale také v autoškole. Bohužel 3D model

se potýká s vysokou poruchovostí a nepřesností krokových motorů, a zvolením materiálu

s příliš velkou hustotou, a tím způsobenou velkou hmotností. Také pro budoucí využití je

překážkou cena zhotovení jednoho kusu. Ta činí přibližně 15 119 Kč.

### ZDROJE

[1] LIBERAL, Alberto. Linux Driver Development with Raspberry Pi. 1. vydání. Madrid:

Alberto Liberal, 2021. ISBN 979-85-161-2068-8.

[2] SCHRÖTER, Zdeněk. Autoškola? Pohodlně!. 30. vydání. Plzeň: Helena Schröterová,

2023. ISBN 978-80-908237-4-7.

[3] PECINOVSKÝ, Rudolf. Python – Kompletní příručka jazyka pro verzi 3.11. 1. vydání.

Praha: Grada Publishing a.s., 2023. ISBN 978-80-271-3891-3.

[4] UPTON, Liz. The Raspberry Pi Launch. Online. Raspberry Pi. 2012. Dostupné z:

https://www.raspberrypi.com/news/the-raspberry-pi-launch/. [cit. 2023-11-20].

[5] BROADCOM CORPORATION. BCM2835 ARM Peripherals. Online. Raspberry Pi.

2012. Dostupné z: https://datasheets.raspberrypi.com/bcm2835/bcm2835-peripherals.pdf. [cit.

2023-11-20].

[6] ARM LIMITED. ARM1176JZF-S Technical Reference Manual. Online. Arm Developer.

2009. Dostupné z: https://developer.arm.com/documentation/ddi0301/latest/. [cit. 2023-11-

20].

[7] WAVESHARE. 1.5inch RGB OLED Module. Online. Waveshare Electronics. 2011.

Dostupné z: https://www.waveshare.com/wiki/1.5inch_RGB_OLED_Module. [cit. 2023-11-

20].

[8] UPTON, Eben. New product launch! Introducing Raspberry Pi Model B+. Raspberry Pi

[online]. 2014. Dostupné z: https://www.raspberrypi.com/news/introducing-raspberry-pi-

model-b-plus/ (https://www.raspberrypi.com/news/introducing-raspberry-pi-model-b-plus/) [cit. 2023-11-20].

[10] AYYUB, Ibrar. Raspberry Pi 2 Model B – BCM2836 PDF Download. Online. Raspberry

Pi. 2015. Dostupné z: https://projects-raspberry.com/raspberry-pi-2-model-b-bcm2836-pdf-

download/. (https://projects-raspberry.com/raspberry-pi-2-model-b-bcm2836-pdf-download/) [cit. 2023-11-20].

[12] RASPBERRY PI LTD. Raspberry Pi 2 Model B. Online. Raspberry Pi. 2015. Dostupné

z: https://www.raspberrypi.com/products/raspberry-pi-2-model-b/. [cit. 2023-11-20].

[13] LYNN, Helen. Serving the Raspberry Pi 3 launch from a Raspberry Pi 3. Online.

Waveshare Electronics. 2016. Dostupné z: https://www.raspberrypi.com/news/serving-

raspberry-pi-3-launch-raspberry-pi-3/. (https://www.raspberrypi.com/news/serving-raspberry-pi-3-launch-raspberry-pi-3/) [cit. 2023-11-20].

[14] RASPBERRY PI LTD. Raspberry Pi Zero. Online. Raspberry Pi. 2016. Dostupné z:

https://www.raspberrypi.com/products/raspberry-pi-zero/. [cit. 2023-11-20].

[15] QUADE, Jürgen a KUNST, Eva-Katharina. Operating the Raspberry Pi 3 in 64-bit

mode. Online. Raspberry Pi Geek. 2017. Dostupné z: https://www.raspberry-pi-

geek.com/Archive/2017/23/Operating-the-Raspberry-Pi-3-in-64-bit-mode. (https://www.raspberry-pi-geek.com/Archive/2017/23/Operating-the-Raspberry-Pi-3-in-64-bit-mode) [cit. 2023-11-20].

[16] RASPBERRY PI LTD. Raspberry Pi 3 Model B. Online. Raspberry Pi. 2017. Dostupné

z: https://www.raspberrypi.com/products/raspberry-pi-3-model-b/. [cit. 2023-11-20].

[17] CYPRESS SEMICONDUCTOR. BCM43438 Datasheet. Online. Alldatasheet. 2017.
Dostupné | z: | https://pdf1.alldatasheet.com/datasheet-pdf/view/1018493/CYPRESS/

BCM43438.html. (https://pdf1.alldatasheet.com/datasheet-pdf/view/1018493/CYPRESS/%20BCM43438.html) [cit. 2023-11-20].

[18] UPTON, Eben. New product! Raspberry Pi Zero W joins the family. Online. Raspberry

Pi. 2017. Dostupné z: https://www.raspberrypi.com/news/raspberry-pi-zero-w-joins-family/.

[cit. 2023-11-20].

[19] ADAFRUIT. Raspberry Pi Zero W. Online. Adafruit. 2017. Dostupné z:

https://www.adafruit.com/product/3400. [cit. 2023-11-20].

[20] RASPBERRY PI LTD. Raspberry Pi 3 Model A+. Online. Raspberry Pi. C2023.

Dostupné z: https://datasheets.raspberrypi.com/rpi3/raspberry-pi-3-a-plus-product-brief.pdf.

[cit. 2023-11-20].

[21] EDWARDS, Benj. What is HDMI? Online. How-To Geek. 2022. Dostupné z:

https://www.howtogeek.com/778339/what-is-hdmi/. [cit. 2023-11-20].

[22] RASPBERRY PI LTD. Raspberry Pi 3 Model A+. Online. Raspberry Pi. 2018. Dostupné

z: https://www.raspberrypi.com/products/raspberry-pi-3-model-a-plus/. [cit. 2023-11-20].

[23] RASPBERRY PI LTD. Raspberry Pi 3 Model B+. Online. Raspberry Pi. 2018. Dostupné

z: https://www.raspberrypi.com/products/raspberry-pi-3-model-b-plus/. [cit. 2023-11-20].

[24] RASPBERRY PI LTD. Raspberry Pi 4. Online. Raspberry Pi. 2019. Dostupné z:

https://www.raspberrypi.com/products/raspberry-pi-4-model-b/. [cit. 2023-11-20].

[25] RASPBERRY PI LTD. BCM2711 ARM Peripherals. Online. Raspberry Pi. 2022.

Dostupné z: https://datasheets.raspberrypi.com/bcm2711/bcm2711-peripherals.pdf. [cit. 2023-

11-20].

[26] RASPBERRY PI LTD. Raspberry Pi 4 Tech Specs. Online. Raspberry Pi. 2020.

Dostupné z: https://www.raspberrypi.com/products/raspberry-pi-4-model-b/specifications/.

[cit. 2023-11-20].

[27] UPTON, Eben. 8GB Raspberry Pi 4 on sale now at $75. Online. Raspberry Pi. 2020.

Dostupné z: https://www.raspberrypi.com/news/8gb-raspberry-pi-4-on-sale-now-at-75/. [cit.

2023-11-20].

[28] UPTON, Eben. Raspberry Pi 400: the $70 desktop PC. Online. Raspberry Pi. 2020.

Dostupné z: https://www.raspberrypi.com/news/raspberry-pi-400-the-70-desktop-pc/. [cit.

2023-11-20].

[29] RASPERRY PI LTD. Raspberry Pi 400 Tech Specs. Online. Raspberry Pi. 2020.

Dostupné z: https://www.raspberrypi.com/products/raspberry-pi-400/specifications/. [cit.

2023-11-20].

[30] | RASPERRY | PI | LTD. | RP3A0. | Online. | Github. | 2022. | Dostupné | z:

https://github.com/raspberrypi/documentation/blob/develop/documentation/asciidoc/computer

s/processors/rp3a0.adoc. (https://github.com/raspberrypi/documentation/blob/develop/documentation/asciidoc/computers/processors/rp3a0.adoc) [cit. 2023-11-20].

[31] RASPERRY PI LTD. Raspberry Pi Zero 2 W. Online. Raspberry Pi. 2022. Dostupné z:

https://www.raspberrypi.com/products/raspberry-pi-zero-2-w/. [cit. 2023-11-20].

[32] RASPERRY PI LTD. RP2040 Tech Specs. Online. Raspberry Pi. 2021. Dostupné z:

https://www.raspberrypi.com/products/rp2040/specifications/. [cit. 2023-11-20].

[33] RASPERRY PI LTD. Rasperry Pi Pico. Online. Raspberry Pi. 2021. Dostupné z:

https://www.raspberrypi.com/products/raspberry-pi-pico/. [cit. 2023-11-20].

[34] UPTON, Eben. Introducing: Raspberry Pi 5!. Online. Raspberry Pi. C2023. Dostupné z:

https://www.raspberrypi.com/news/introducing-raspberry-pi-5/. [cit. 2023-11-20].

[35] RASPBERRY PI LTD. Raspberry Pi 5. Online. Raspberry Pi. C2023. Dostupné z:

https://www.raspberrypi.com/products/raspberry-pi-5/. [cit. 2023-11-20].

[36] CIRCUIT DIGEST. The New Raspberry Pi 5 is here: Faster than Ever. Online. Circuit

Digest. C2023. Dostupné z: https://circuitdigest.com/news/the-new-raspberry-pi-5-is-here-

faster-than-ever. (https://circuitdigest.com/news/the-new-raspberry-pi-5-is-here-faster-than-ever) [cit. 2023-11-20].

[38] RASPBERRY PI LTD. Raspberry Pi OS. Online. Raspberry Pi. 2012. Dostupné z:

https://www.raspberrypi.com/documentation/computers/os.html#introduction. [cit. 2023-12-

02].

[39] RASPBERRY PI LTD. Configuration. Online. Raspberry Pi. 2012. Dostupné z:

https://www.raspberrypi.com/documentation/computers/configuration.html#the-raspi-config-

tool. (https://www.raspberrypi.com/documentation/computers/configuration.html#the-raspi-config-tool) [cit. 2023-12-02].

[40] UBUNTU MATE TEAM. Ubuntu MATE. Online. Ubuntu MATE. 2014. Dostupné z:

https://ubuntu-mate.org/. [cit. 2023-12-02].

[41] MICROSOFT CORPORATION. Setting up a Raspberry Pi. Online. Microsoft Learn.

C2023. Dostupné z: https://learn.microsoft.com/en-us/previous-versions/windows/iot-core/

tutorials/rpi. (https://learn.microsoft.com/en-us/previous-versions/windows/iot-core/%20tutorials/rpi) [cit. 2023-12-02].

[42] KLIMASZEWSKI, Steev. Raspberry Pi 4. Online. Kali. C2023. Dostupné z:

https://www.kali.org/docs/arm/raspberry-pi-4/. [cit. 2023-12-02].

[43] GUPTA, Vibha. 10 Best Programming Languages for Raspberry Pi. Online. Alma Better.

C2023. Dostupné z: https://www.almabetter.com/bytes/articles/best-programming-languages-

for-raspberry-pi. (https://www.almabetter.com/bytes/articles/best-programming-languages-for-raspberry-pi) [cit. 2023-12-10].

[44] WARD, Jessica. List of Raspberry Pi Video Players and How to Play Guide. Online.

Raspberry Pi Starter Kits. 2018. Dostupné z: https://www.raspberrypistarterkits.com/guide/

raspberry-pi-video-player/. (https://www.raspberrypistarterkits.com/guide/%20raspberry-pi-video-player/) [cit. 2023-12-10].

[45] SUNFOUNDER. Traffic Light Module. Online. SunFounder. C2023. Dostupné z:

https://docs.sunfounder.com/projects/ultimate-sensor-kit/en/latest/components_basic/23-

component_traffic.html. (https://docs.sunfounder.com/projects/ultimate-sensor-kit/en/latest/components_basic/23-component_traffic.html) [cit. 2023-12-10].

[46] SOFTWARE IN THE PUBLIC INTEREST, INC. UnattendedUpgrades. Online. Debian

Wiki. C2023. Dostupné z: https://wiki.debian.org/UnattendedUpgrades. [cit. 2023-12-10].

[47] PYTHON SOFTWARE FOUNDATION. Os — Miscellaneous operating system
interfaces. | Online. | Python | Documentation. | C2023. | Dostupné | z:

https://docs.python.org/3/library/os.html#module-os. [cit. 2023-12-10].

[48] PYTHON SOFTWARE FOUNDATION. RPi.GPIO 0.7.1. Online. PyPI. C2023.

Dostupné z: https://pypi.org/project/RPi.GPIO/. [cit. 2023-12-10].

[49] PYTHON SOFTWARE FOUNDATION. Logging — Logging facility for Python. Online.

Python Documentation. C2023. Dostupné z: https://docs.python.org/3/library/logging.html.

[cit. 2023-12-10].

[50] PYTHON SOFTWARE FOUNDATION. Time — Time access and conversions. Online.
Python | Documentation. | C2023. | Dostupné | z: | https://docs.python.org/3/library/

time.html?highlight=time#module-time. (https://docs.python.org/3/library/%20time.html?highlight=time#module-time) [cit. 2023-12-10].

[51] CLARK, Jeffrey. Pillow (PIL Fork) 10.2.0 documentation. Online. Pillow. C2023.

Dostupné z: https://pillow.readthedocs.io/en/stable/index.html. [cit. 2023-12-13].

[52] PYTHON SOFTWARE FOUNDATION. Subprocess — Subprocess management.

Online. Python Documentation. C2023. Dostupné z: https://docs.python.org/3/library/

subprocess.html. (https://docs.python.org/3/library/%20subprocess.html) [cit. 2023-12-10].

[53] SCHIMANSKY, Tom. CustomTkinter. Online. CustomTkinter. C2023. Dostupné z:

https://customtkinter.tomschimansky.com/. [cit. 2023-12-13].

[54] | FORCIER, | Jeff. | Paramiko. | Online. | Paramiko. | C2023. | Dostupné | z:

https://www.paramiko.org/. [cit. 2023-12-13].

[55] SSH COMMUNICATIONS SECURITY INC. What is SSH (Secure Shell)? Online. PAM
solutions, Key Management System, Secure File Transfers | SSH. C2023. Dostupné z:

https://www.ssh.com/academy/ssh. [cit. 2023-12-13].

[56] CLOUDFLARE, INC. What is SSH? | Secure Shell (SSH) protocol. Online. Connect,
Protect | and | Build | Everywhere | | | Cloudflare. | C2023. | Dostupné | z:

https://www.cloudflare.com/learning/access-management/what-is-ssh/. [cit. 2023-12-13].

[57] RASPBERRY PI LTD. Raspberry Pi. Online. Raspberry Pi Foundation. C2023.

Dostupné z: https://www.raspberrypi.org/about/. [cit. 2023-12-13].

[58] VILCHES, Jose. Interview with Raspberry's Founder Eben Upton. Online. TechSpot.

C1998 - 2023. Dostupné z: https://www.raspberrypi.org/about/. [cit. 2023-12-13].

[59] JAGGER, Paul. Interview with Eben Upton CBE. Online. Oral Histories of IT and Tech.

C2023. Dostupné z: https://archivesit.org.uk/interviews/eben-upton-cbe/. [cit. 2023-12-13].

[60] TIWARI, Ashish. What Is OLED And How Does It Work? Online. Science ABC. C2023.
Dostupné | z: | https://www.scienceabc.com/innovation/what-is-oled-and-how-does-it-

work.html. (https://www.scienceabc.com/innovation/what-is-oled-and-how-does-it-work.html) [cit. 2023-12-13].

[61] TYSON, Jeff. How LCDs Work. Online. HowStuffWorks - Learn How Everything

Works!. C2023. Dostupné z: https://electronics.howstuffworks.com/lcd.htm. [cit. 2023-12-

13].

[62] ESET. Co je DDoS útok a jaká je ochrana? Online. ESET. C1992 - 2023. Dostupné z:

https://www.eset.com/cz/ddos-utok/. [cit. 2023-12-13].

[63] MDN CONTRIBUTORS. Object-oriented programming. Online. MDN Web Docs.

C1998-2023. Dostupné z: https://developer.mozilla.org/en-US/docs/Learn/JavaScript/Objects/

Object-oriented_programming. (https://developer.mozilla.org/en-US/docs/Learn/JavaScript/Objects/%20Object-oriented_programming) [cit. 2023-12-13].

[64] SPARKES, Matthew. What does Wi-Fi stand for? Online. New Scientist. C2023.

Dostupné z: https://www.newscientist.com/question/what-does-wi-fi-stand-for/. [cit. 2023-12-

13].

[65] HIRZEL, Timothy. Basics of PWM (Pulse Width Modulation). Online. Arduino Docs.

C2023. Dostupné z: https://docs.arduino.cc/learn/microcontrollers/analog-output/. [cit. 2023-

12-13].

[66] TOWNSEND, Kevin. Introduction to Bluetooth Low Energy. Online. Adafruit Learning
System. | C2023. | Dostupné | z: | https://learn.adafruit.com/introduction-to-bluetooth-low-
energy/introduction. (https://learn.adafruit.com/introduction-to-bluetooth-low-energy/introduction) [cit. 2023-12-13].

### SEZNAM POUŽITÝCH ZKRATEK

3D | Trojdimenzionální
ABS | Acrylonitril-butadien-styren
ARM | Advanced RICS Machines – architektura procesorů s malou spotřebou energie
BLE | Bluetooth Low Energy – bezdrátová komunikační technologie s velmi malou spotřebou energie [66]
CNC | Computer Numerical Control (stroje řízené počítačem)
DDoS | Distributed Denial-of-service – pomocí mnoha zařízení se útočník snaží zahltit cíl útoku. [62]
GB | Gigabyte
Gbps | Gigabits per second
GND | Ground (uzemnění)
GPIO | General-purpose input/output
GUI | Graphical User Interface (grafické uživatelské rozhraní)
HDMI | High-Definition Multimedia Interface – rozhraní pro přenos obrazového a
zvukového signálu v digitálním formátu pomocí jednoho kabelu [21]
IoT | Internet of Things (internet věcí) – síť zařízení, která jsou navzájem bezdrátově propojena a mohou si vyměňovat data [41]
LCD | Liquid-crystal display – typ displeje skládající se z barevných pixelů seřazených před zdrojem světla [61]
LED | Light-Emitting Diode (elektroluminiscenční dioda) – dioda, která vyzařuje světlo
MB | Megabyte
OLED | Organic Light-Emitting Diode – displej obsahující pixely, z nichž úplně každý má vlastní zdroj světla, a proto lépe vyobrazuje černou barvu [60]
OOP | Object-oriented programming – typ programování vytvářející program pomocí bloků kódu, které mezi sebou mohou navzájem komunikovat
OS | Operating System (operační systém)
PCB | Printed circuit board (deska plošných spojů)
PWM | Pulse-width modulation (pulzně šířková modulace) – modulace pro přenos analogového signálu pomocí dvouhodnotového signálu [65]
RAM | Random Access Memory (operační paměť)
RGB | Red Green Blue – typ displeje, který používá barevné zobrazení pomocí míchání červené, zelené a modré
SD | Secure Digital
SoC | System on a chip – integrovaný obvod zahrnující všechny elektronické součásti počítače do jednoho čipu

SSH | Secure Shell
TFT | Thin-film-transistor (tenkovrstvý tranzistor
UI | User Interface (Uživatelské rozhraní)
USB | Universal Serial Bus (univerzální sériová sběrnice)
VUT | Vysoké učení technické v Brně
Wi-Fi | Bezdrátový přenos dat pomocí rádiových vln založený na standardech IEEE 802.11 [64]
WLAN | Wireless Local Area Network (bezdrátová místní síť)

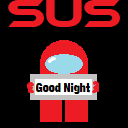
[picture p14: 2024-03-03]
src/OLED_Module_Code/RaspberryPi/python/pic/sus.bmp

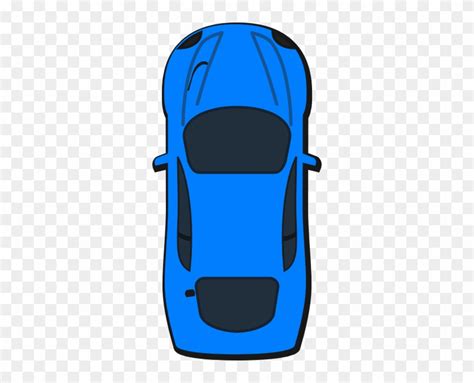
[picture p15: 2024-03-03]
src/obrázky/krizovatky/ruzove_auto.jpg

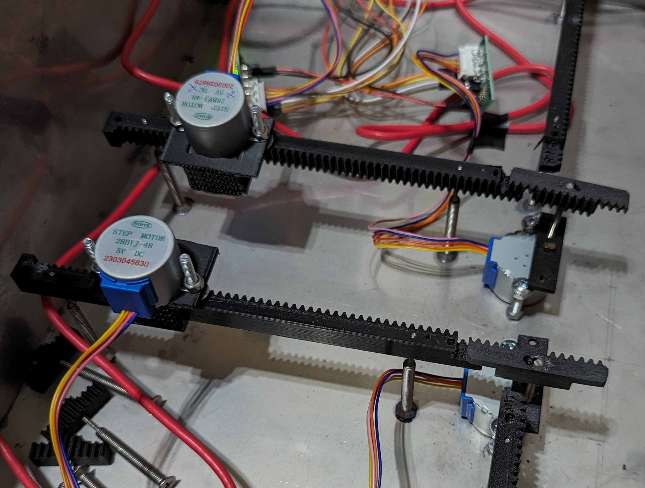
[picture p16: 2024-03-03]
src/obrázky/ozubene_kolejnice.jpg

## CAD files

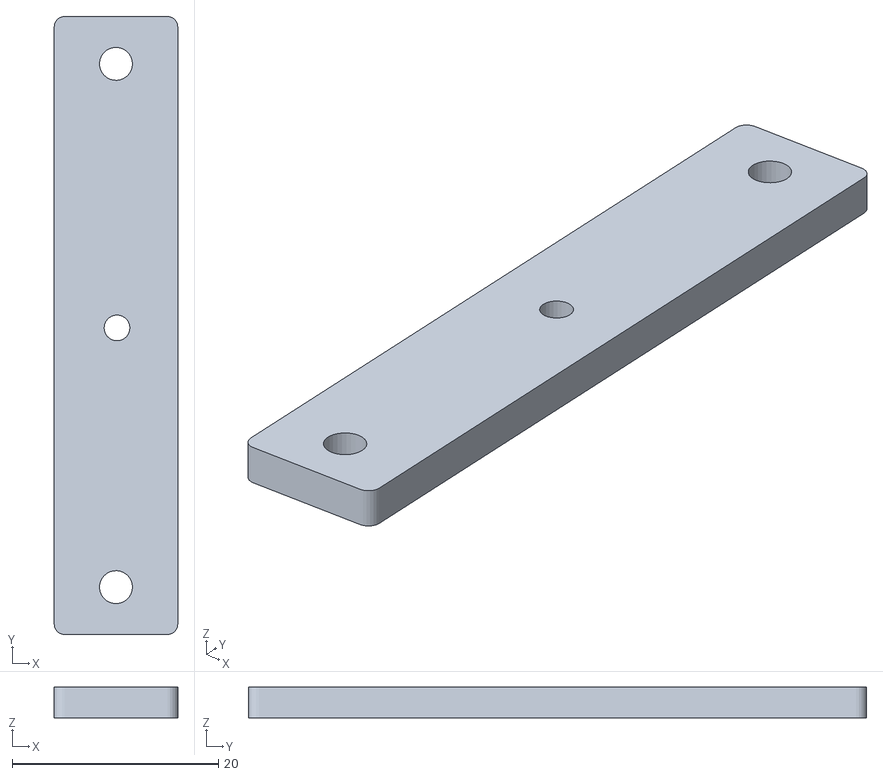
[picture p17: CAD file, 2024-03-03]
src/modely/long_rail_holder.stl
12.0 x 60.0 x 3.00

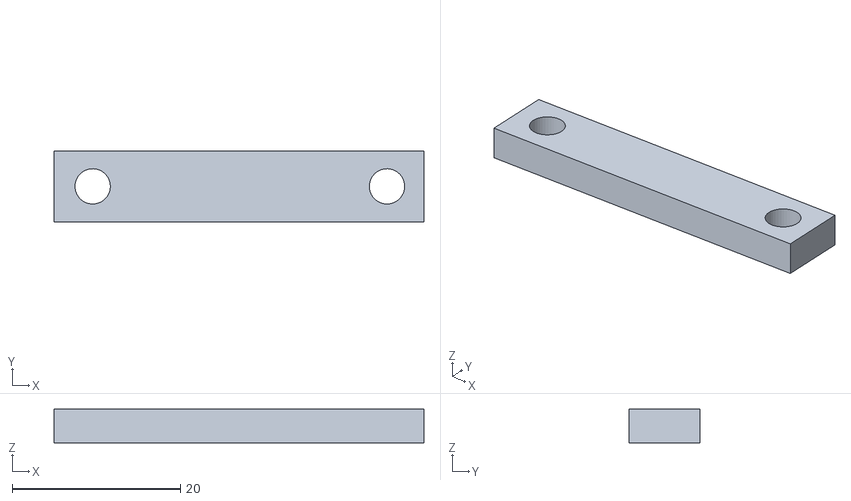
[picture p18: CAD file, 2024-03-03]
src/modely/stator.stl
44.0 x 8.50 x 4.00

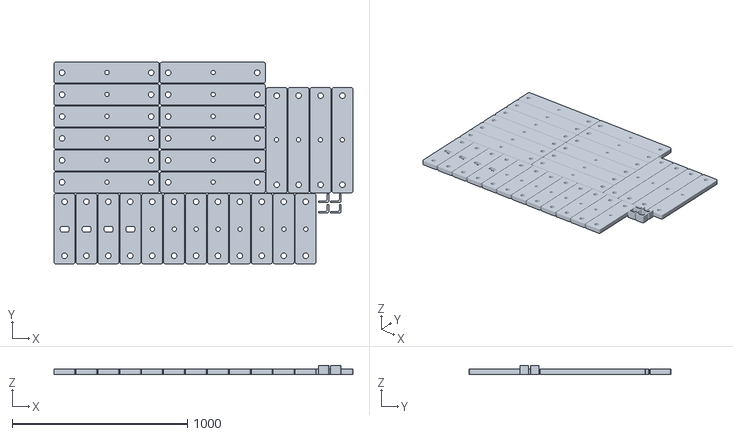
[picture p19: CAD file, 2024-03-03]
src/modely/holders.stl
1705.0 x 1150.0 x 50.0

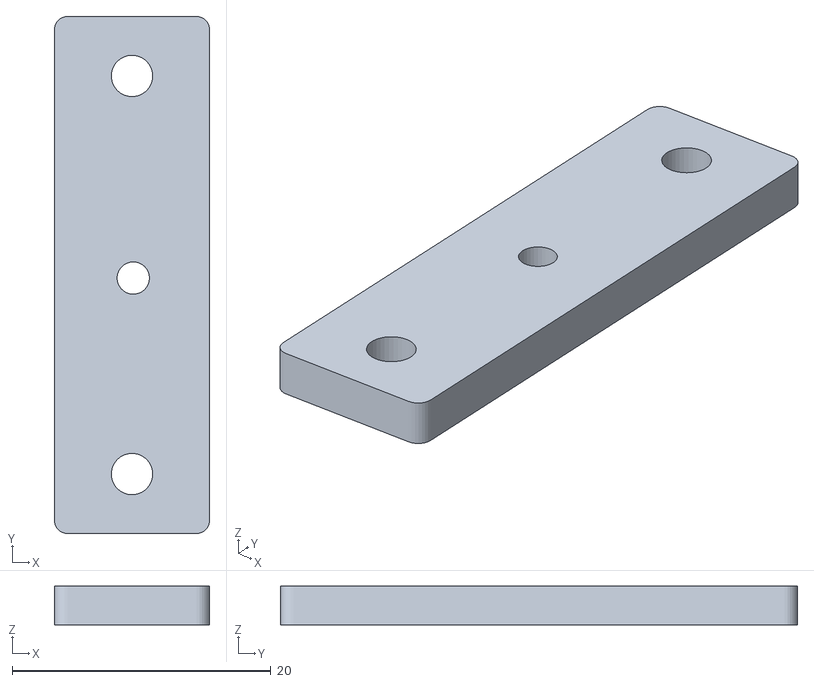
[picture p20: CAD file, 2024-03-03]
src/modely/short_rail_holder.stl
12.0 x 40.0 x 3.00

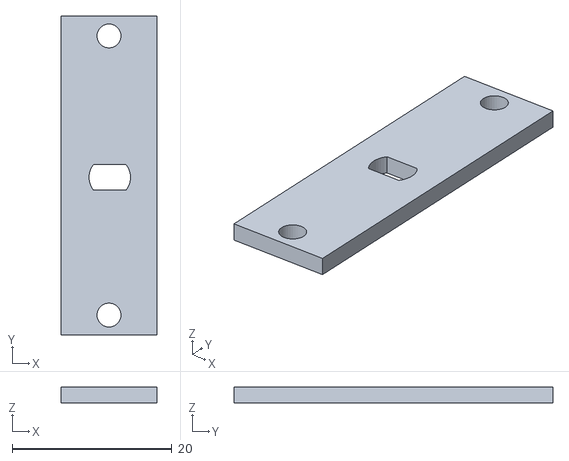
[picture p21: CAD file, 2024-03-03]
src/modely/rotor_upevneni.stl
12.0 x 40.0 x 2.00

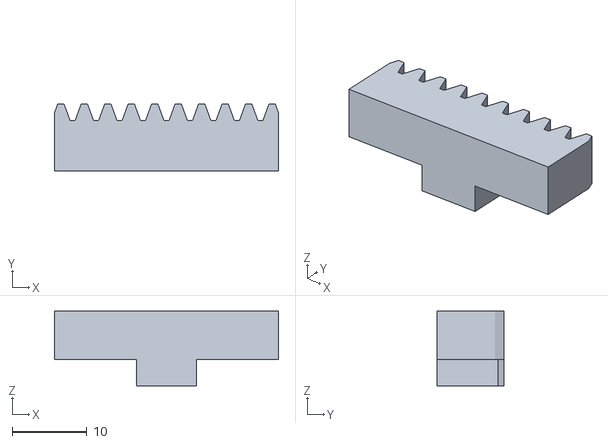
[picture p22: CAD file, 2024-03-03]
src/modely/rotor_rack.stl
30.0 x 9.00 x 10.0

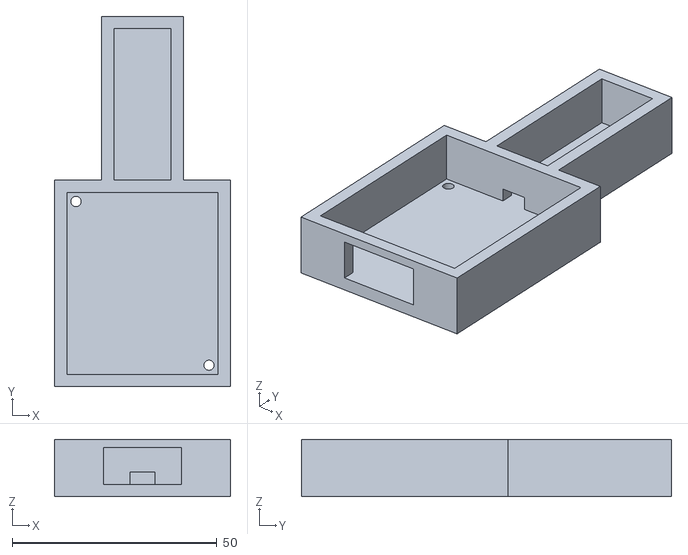
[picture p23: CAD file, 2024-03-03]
src/modely/semafor_1.stl
43.0 x 90.5 x 14.0

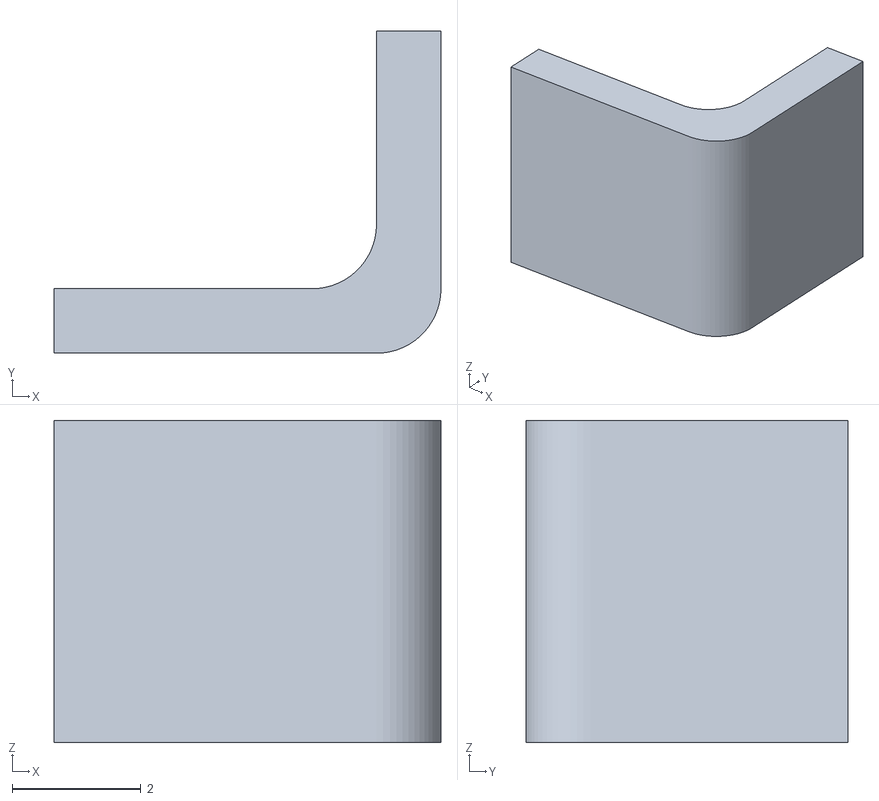
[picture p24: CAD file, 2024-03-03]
src/modely/cover_helper.stl
6.00 x 5.00 x 5.00

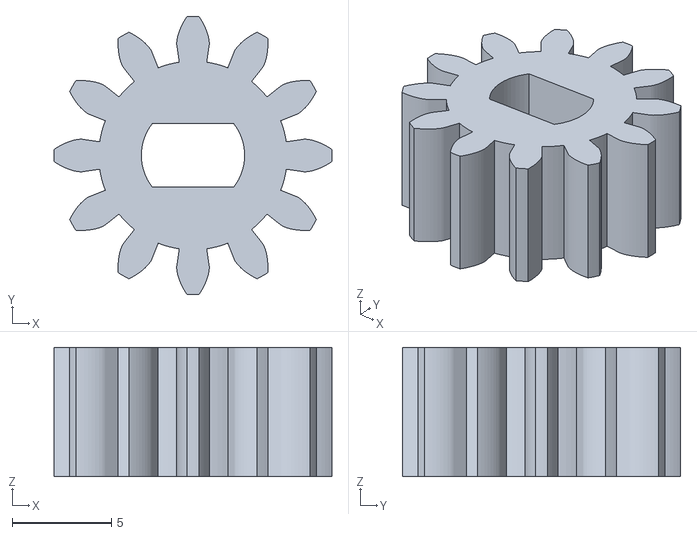
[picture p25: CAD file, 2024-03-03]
src/modely/wheel.stl
14.0 x 14.0 x 6.50

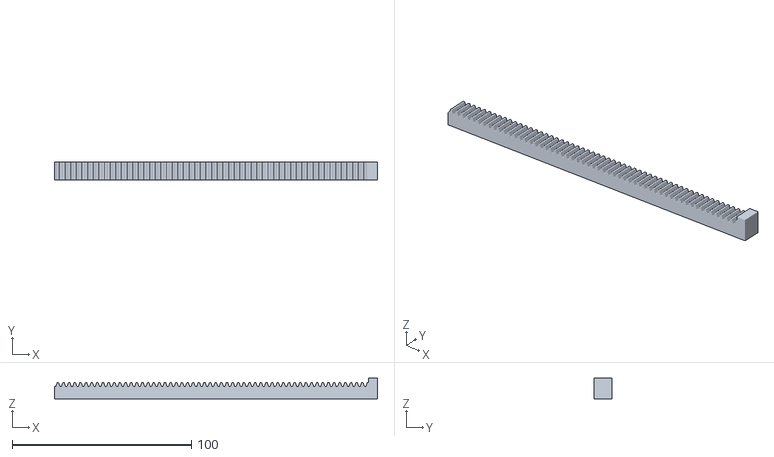
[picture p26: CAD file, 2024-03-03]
src/modely/rack_long.stl
180.0 x 10.0 x 11.5

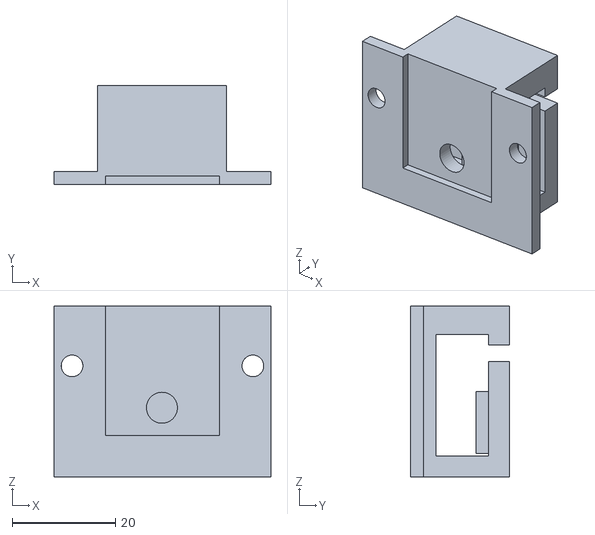
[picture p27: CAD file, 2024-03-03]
src/modely/motor_add2.stl
42.0 x 19.1 x 33.0

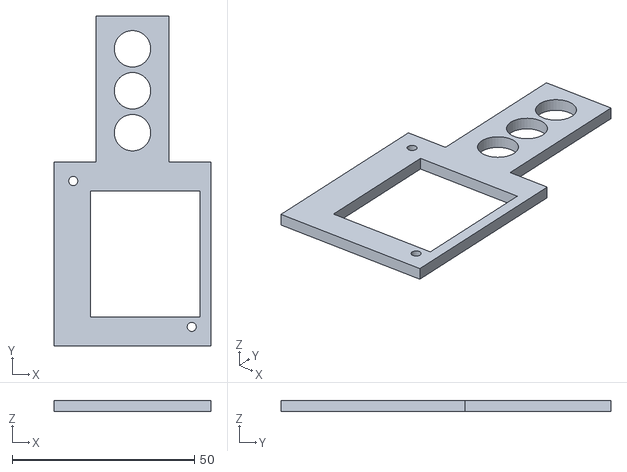
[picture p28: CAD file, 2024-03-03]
src/modely/semafor_2.stl
43.0 x 90.5 x 3.00

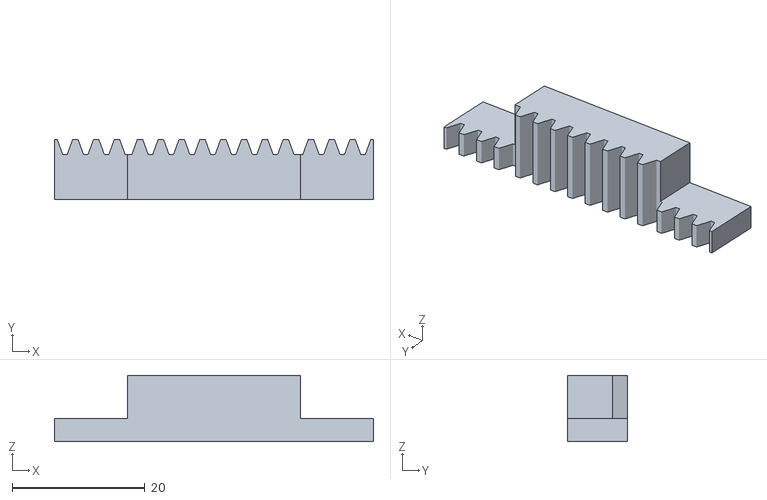
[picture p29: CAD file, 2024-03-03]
src/modely/center_rack.stl
48.1 x 9.00 x 10.0

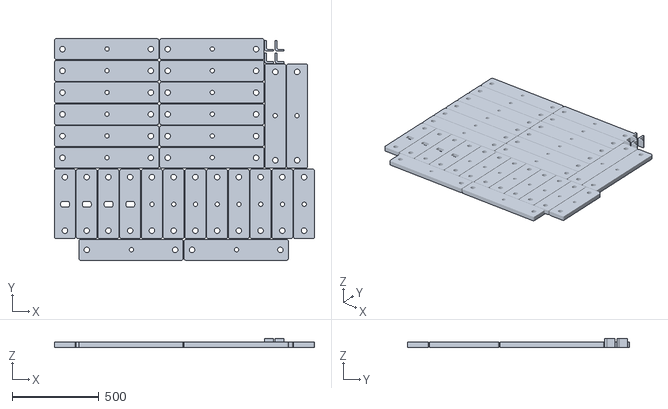
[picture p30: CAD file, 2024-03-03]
src/modely/holders2.stl
1495.0 x 1274.5 x 50.0

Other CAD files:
src/modely/motor_uchyt.stl
src/modely/motor_add.stl

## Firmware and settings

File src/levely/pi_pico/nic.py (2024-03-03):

import machine
import time

# Define the pin numbers for the traffic lights
YELLOW_PIN = 1
YELLOW_PIN2 = 4
YELLOW_PIN3 = 7
YELLOW_PIN4 = 10

# Initialize the GPIO pins
yellow_led = machine.Pin(YELLOW_PIN, machine.Pin.OUT)
yellow_led2 = machine.Pin(YELLOW_PIN2, machine.Pin.OUT)
yellow_led3 = machine.Pin(YELLOW_PIN3, machine.Pin.OUT)
yellow_led4 = machine.Pin(YELLOW_PIN4, machine.Pin.OUT)

# Function to control the traffic lights
def run_traffic_lights():
        # Yellow light
        yellow_led.on()
        yellow_led2.on()
        yellow_led3.on()
        yellow_led4.on()
        time.sleep(1)  # Wait for 1 seconds

        yellow_led.off()
        yellow_led2.off()
        yellow_led3.off()
        yellow_led4.off()
        time.sleep(1)  # Wait for 1 seconds

# Run the traffic lights
while True:    
        run_traffic_lights()

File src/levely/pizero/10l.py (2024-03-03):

import sys
import os
import RPi.GPIO as GPIO
import spidev
import logging  
import time
logging.basicConfig(level=logging.DEBUG)

# Nastavení pinů pro řadič UNL2003
IN1 = 17
IN2 = 18
IN3 = 23
IN4 = 22

# Nastavení pinů pro řadič ULN2003_2
IN5 = 16
IN6 = 7
IN7 = 5
IN8 = 6

# Nastavení režimu pinů GPIO
GPIO.setmode(GPIO.BCM)
GPIO.setup(IN1, GPIO.OUT)
GPIO.setup(IN2, GPIO.OUT)
GPIO.setup(IN3, GPIO.OUT)
GPIO.setup(IN4, GPIO.OUT)
GPIO.setup(IN5, GPIO.OUT)
GPIO.setup(IN6, GPIO.OUT)
GPIO.setup(IN7, GPIO.OUT)
GPIO.setup(IN8, GPIO.OUT)

# Funkce pro posun motoru vpravo o jeden krok
def step_forward(delay):
    GPIO.output(IN1, GPIO.HIGH)
    time.sleep(delay)
    GPIO.output(IN1, GPIO.LOW)
    GPIO.output(IN2, GPIO.HIGH)
    time.sleep(delay)
    GPIO.output(IN2, GPIO.LOW)
    GPIO.output(IN3, GPIO.HIGH)
    time.sleep(delay)
    GPIO.output(IN3, GPIO.LOW)
    GPIO.output(IN4, GPIO.HIGH)
    time.sleep(delay)
    GPIO.output(IN4, GPIO.LOW)

# Funkce pro posun motoru vlevo o jeden krok
def step_back(delay):
    GPIO.output(IN4, GPIO.HIGH)
    time.sleep(delay)
    GPIO.output(IN4, GPIO.LOW)
    GPIO.output(IN3, GPIO.HIGH)
    time.sleep(delay)
    GPIO.output(IN3, GPIO.LOW)
    GPIO.output(IN2, GPIO.HIGH)
    time.sleep(delay)
    GPIO.output(IN2, GPIO.LOW)
    GPIO.output(IN1, GPIO.HIGH)
    time.sleep(delay)
    GPIO.output(IN1, GPIO.LOW)
# Funkce pro posun motoru 2 vpravo o jeden krok
def step_forward2(delay):
    GPIO.output(IN5, GPIO.HIGH)
    time.sleep(delay)
    GPIO.output(IN5, GPIO.LOW)
    GPIO.output(IN6, GPIO.HIGH)
    time.sleep(delay)
    GPIO.output(IN6, GPIO.LOW)
    GPIO.output(IN7, GPIO.HIGH)
    time.sleep(delay)
    GPIO.output(IN7, GPIO.LOW)
    GPIO.output(IN8, GPIO.HIGH)
    time.sleep(delay)
    GPIO.output(IN8, GPIO.LOW)
# Funkce pro posun motoru 2 vlevo o jeden krok
def step_back2(delay):
    GPIO.output(IN8, GPIO.HIGH)
    time.sleep(delay)
    GPIO.output(IN8, GPIO.LOW)
    GPIO.output(IN7, GPIO.HIGH)
    time.sleep(delay)
    GPIO.output(IN7, GPIO.LOW)
    GPIO.output(IN6, GPIO.HIGH)
    time.sleep(delay)
    GPIO.output(IN6, GPIO.LOW)
    GPIO.output(IN5, GPIO.HIGH)
    time.sleep(delay)
    GPIO.output(IN5, GPIO.LOW)

# Hlavní program
if __name__ == "__main__":
    try:
        logging.basicConfig(level=logging.DEBUG)

        # Nastavení zpoždění (minimální zpoždění pro nejvyšší rychlost motoru)
        delay = 0.002

        # Vynulování motoru
        GPIO.output(IN1, GPIO.LOW)
        GPIO.output(IN2, GPIO.LOW)
        GPIO.output(IN3, GPIO.LOW)
        GPIO.output(IN4, GPIO.LOW)
        GPIO.output(IN5, GPIO.LOW)
        GPIO.output(IN6, GPIO.LOW)
        GPIO.output(IN7, GPIO.LOW)
        GPIO.output(IN8, GPIO.LOW)
        i=0
        while i<10:
            step_back2(delay)
            i += 1
    except KeyboardInterrupt:
        # Ukončení programu při stisku klávesy Ctrl+C
        logging.info("ctrl + c:")
        GPIO.cleanup()
